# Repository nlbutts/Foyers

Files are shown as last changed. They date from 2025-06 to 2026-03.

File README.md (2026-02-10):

# Foyers / BackPorch Project

The Foyers/BackPorch system is an STM32-based hardware ecosystem designed for FRC robot sensing and control, featuring CAN communication with a built-in bootloader.

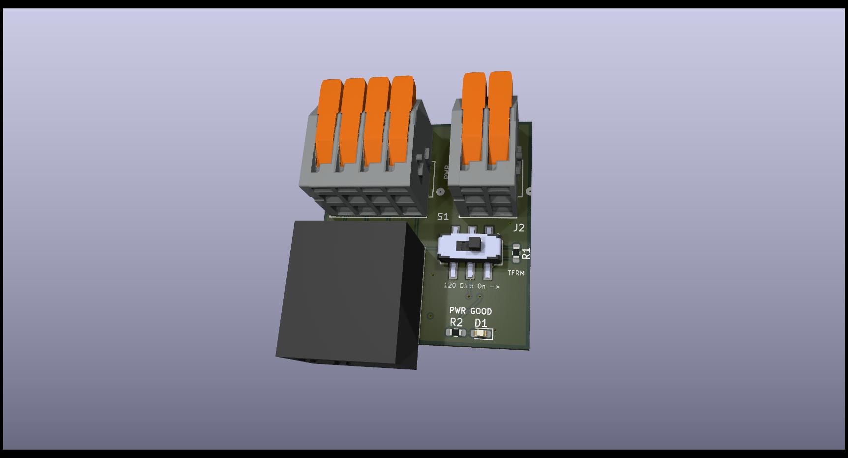
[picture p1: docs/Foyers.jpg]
Foyer Board


## Hardware Overview

### Foyer Distribution Board
The Foyer board serves as the primary distribution point for the system. 
- **Power & CAN Input**: Connects to the main robot power and CAN bus.
- **Power & CAN Exit**: Provides a pass-through for daisy-chaining CAN and power to subsequent devices.
- **Node Interface**: Distributes power and CAN to the BackPorch and sensor nodes.

### BackPorch Main Board
The BackPorch is the central controller board, based on the STM32G0B1 microcontroller. It handles high-level CAN communication, sensor aggregation, and basic power management.

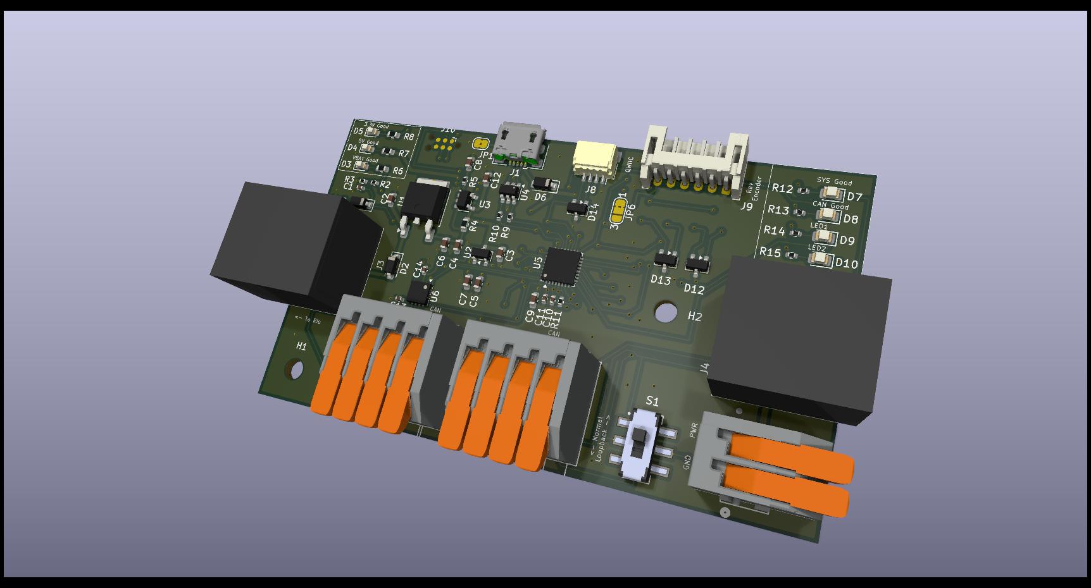
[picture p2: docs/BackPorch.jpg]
BackPorch Header


#### Main Connectors & Pinouts

| Ref | Type | Function | Mating Part |
| --- | --- | --- | --- |
| **J4** | RJ45 | CAN Bus | Standard RJ45 Plug |
| **J9** | JST PH 6-pin | Rev Through Bore Encoder | JST PHR-6 |
| **J10** | USB Micro B | Power / Debug | Standard Micro-USB |
| **J1/J2**| Wago 2601 | Power Input (VBAT/GND) | 24-16 AWG Wire |
| **J3** | Wago 2601 | Motor Output | 24-16 AWG Wire |
| **J6** | Tag-Connect | SWD Programming | TC2030-IDC |

**J4 (RJ45) CAN Pinout:**
- **Pin 1**: CAN High
- **Pin 2**: CAN Low
- **Pin 3**: CAN High Loopback
- **Pin 4**: VBAT
- **Pin 5**: VBAT
- **Pin 6**: Can Low Loopback
- **Pin 7**: GND
- **Pin 8**: GND

**J9 (Rev Through Bore Encoder) Pinout:**
Compatible with the [REV Through Bore Encoder](https://docs.revrobotics.com/rev-crossover-products/sensors/tbe).
- **Pin 1**: 5V Power
- **Pin 2**: Absolute Position (Duty Cycle)
- **Pin 3**: Incremental Channel A
- **Pin 4**: Incremental Channel B
- **Pin 5**: Index (Optional)
- **Pin 6**: GND

### SimpleTOF Board
A compact Time-of-Flight (ToF) distance sensor breakout designed to interface with the BackPorch.

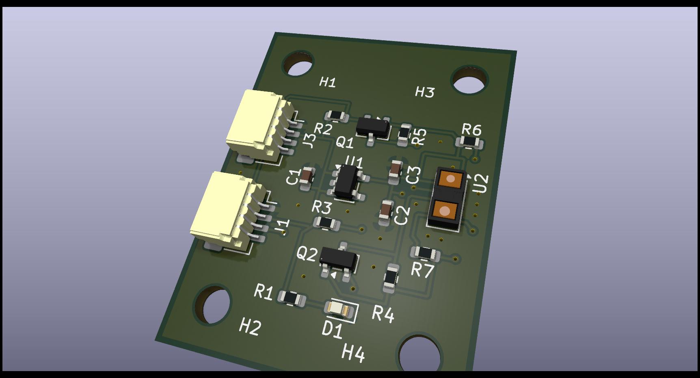
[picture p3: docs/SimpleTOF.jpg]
SimpleTOF


## Software Setup

### Development Environment
This project uses the official STM32 development workflow:

1.  **STM32CubeMX**: Used for low-level hardware configuration (GPIO, CAN, Timers).
    - Open the `.ioc` files in the `software/backporch` or `software/bootloader` directories to modify the hardware configuration.
    - Generate code to update the underlying HAL drivers.
2.  **Visual Studio Code**: The recommended IDE for code development.
    - Use the **STM32 VS Code Extension** to compile the project.
    - Ensure `arm-none-eabi-gcc` is installed and in your PATH.
    - Build using the `CMake` workflow provided by the extension.

## Bootloader & Monitoring Utility

The `software/can_mon/bp_debug.py` program is a multi-purpose Python utility for interacting with the hardware over CAN.

### Script Purpose
- **CAN Monitor**: Provides a real-time GUI to view telemetry from discovered devices (Voltage, Current, Temp, Distance, Encoder position).
- **Firmware Updater**: Acts as the host tool for the CAN bootloader, allowing you to stream `.bin` files to a target device ID and commit them to flash.
- **Status Broadcasts**: Decodes the WPILib-formatted CAN frames used by the system.

### Usage
```bash
python software/can_mon/bp_debug.py
```
*Note: Requires `python-can` and `tkinter` libraries. Ensure your CAN adapter is configured (default: SLSAN on COM5).*

## System Architecture

System Architecture

The system follows a modular architecture where multiple sensor nodes (Foyers) communicate with the BackPorch controller over a shared CAN bus, which then interfaces with the Robot Controller.

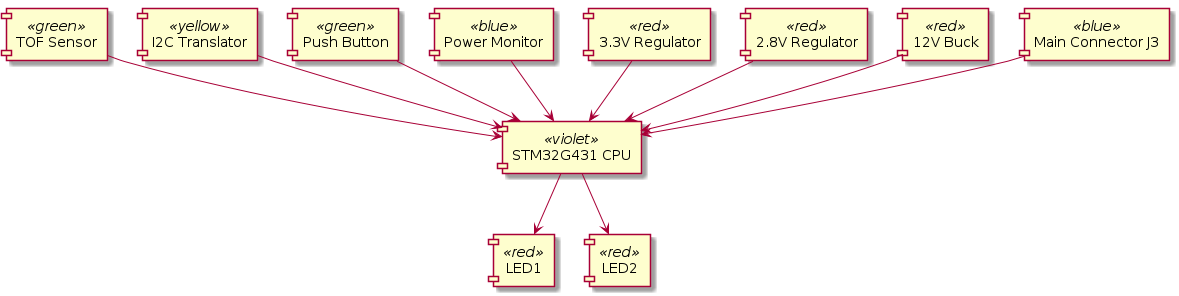
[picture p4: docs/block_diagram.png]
Block Diagram

These are similar to the SWYFT CAN wiring devices

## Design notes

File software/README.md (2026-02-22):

# STM32G0B1 CAN Bootloader

This project implements a CAN-based bootloader for the STM32G0B1 using the WPIlib CAN addressing scheme.

## Overview
- **Bootloader Size**: 32KB (`0x08000000` - `0x08007FFF`)
- **Application App Size**: 96KB (`0x08008000` - `0x0801FFFF`)
- **RAM Buffer**: 96KB Reserved at `0x2000C000`

## CAN Protocol
The bootloader uses 29-bit Extended IDs following the WPIlib format.
- **Device Type**: `10` (Miscellaneous)
- **Manufacturer**: `42` (Custom)
- **Device ID**: `0` (Default)

### CAN ID Structure
| Bits [28:24] | Bits [23:16] | Bits [15:10] | Bits [9:6] | Bits [5:0] |
|---|---|---|---|---|
| Device Type  | Manufacturer | API Class | API Index  | Device ID  |
| `0x0A` (10)  | `0x2A` (42)  | *Variable* | `0` | `0` |

### API Classes
1. **Control (0x01)**: Command and Status operations (Bootloader).
2. **Data (0x02)**: Streaming binary application data (Bootloader).
5. **Status (0x05)**: Application runtime status messages.

### Commands
#### 1. Start Session
Prepare bootloader to receive new data.
- **ID**: `0x0A2A0400` (Class 1)
- **Data[0]**: `0x01` (CMD_START)
- **Response**: `0xAA 0x00 ...` (ACK)

#### 2. Streaming Data
Send application binary in 8-byte chunks.
- **ID**: `0x0A2A0800` (Class 2)
- **Data**: `[Bytes 0-7]`
- **Note**: Must start sending from the beginning of the binary file.

#### 3. Commit & Flash
Verify integrity and program to Flash.
- **ID**: `0x0A2A0400` (Class 1)
- **Data**: `0x02` (CMD_COMMIT) + `[CRC32 (4 Bytes, Little Endian)]`
- **Response**: 
    - `0xAA 0x01 ...` (Success/Rebooting)
    - `0xAA 0xEE ...` (CRC Failure)

## CRC Verification
The bootloader uses the standard **STM32 Hardware CRC-32** unit.
- **Polynomial**: `0x04C11DB7` (Ethernet Standard)
- **Initial Value**: `0xFFFFFFFF`
- **Input/Output Inversion**: None
- **Input Format**: 32-bit Words (Big Endian logic in terms of word feed, but Little Endian memory. Standard STM32 HAL behavior).

### Calculating CRC for Build
The Host tool must calculate the CRC32 of the binary file to send in the `COMMIT` command.
**Python Example**:
```python
import zlib

def calc_crc(file_path):
    with open(file_path, 'rb') as f:
        data = f.read()
    
    # STM32 CRC-32 is slightly different from zlib.crc32 (which is usually inverted).
    # However, STM32 HAL with Default settings is:
    # Poly: 0x04C11DB7, Init: 0xFFFFFFFF
    # Software equivalent usually requires custom implementation or 'crcmod'.
    # Standard MPEG-2 CRC-32 is often close.
    pass
```
*Note*: The easiest way to verify the CRC algorithm matches is to run a small known binary on the chip and print the calculated CRC via debug, then match your script to it.

### CRC Placement in Binary
For the *Boot-Up Verification* (checking app validity on power-on), the bootloader stores the CRC in a special **Boot Config** flash page at `0x08007800`.
- You **do not** need to embed the CRC in the application binary file itself.
- The Host Tool sends the CRC in the `COMMIT` packet.
- The Bootloader validates the RAM buffer against this CRC.
- If match, it flashes the App **AND** updates the Boot Config with this CRC.

## Testing Walkthrough
1. **Build**: Compile the Bootloader.
2. **Flash**: Load `bootloader.elf` to the target.
3. **Connect**: Use a USB-CAN Adapter (e.g., PCAN, CandleLight) with 500kbps (or configured baud).
4. **Commands**:
    - Send `START` (`0x0A2A0400` -> `01`)
    - Send `DATA` chunks (`0x0A2A0800` -> `...`)
    - Send `COMMIT` (`0x0A2A0400` -> `02 AA BB CC DD`)
5. **Verify**: Device should reboot and run application.

## Application Status Messages (API Class 5)
When running in application mode, the device broadcasts status messages using API Class 5.

### 1. Software Version (Index 0)
- **ID**: `0x0A2A1400`
- **Data**:
    - **Byte 0-3**: Unique 32-bit ID (MurmurHash3 of CPU Serial, Little Endian)
    - **Byte 4**: Version Info
        - Bit 0: Mode (0: Bootloader, 1: Application)
        - Bits 1-3: Major Version
        - Bits 4-7: Minor Version
    - **Byte 5-7**: 24-bit build number (Little Endian)

### 2. General Status (Index 1)
- **ID**: `0x0A2A1440`
- **Data**:
    - **Byte 0-3**: Unique 32-bit ID (MurmurHash3 of CPU Serial, Little Endian)
    - **Byte 4**: Current (mA)
    - **Byte 5-6**: Voltage (mV, Little Endian)
    - **Byte 7**: Temperature (°C)

### 3. TOF Status (Index 2)
- **ID**: `0x0A2A1480`
- **Data**:
    - **Byte 0**: ST TOF API Status
    - **Byte 1**: Bit 0 SDA limit switch, Bit 1 SCL limit switch
    - **Byte 2-3**: Distance (mm, Little Endian)
    - **Byte 4-5**: Ambient Mcps (Little Endian)
    - **Byte 6-7**: Signal Mcps (Little Endian)

### 4. Encoder Status (Index 3)
- **ID**: `0x0A2A14C0`
- **Data**:
    - **Byte 0-1**: Encoder 1 Absolute Position (0.01°, Little Endian)
    - **Byte 2-3**: Encoder 1 Incremental Position (counts, Little Endian)
    - **Byte 4-5**: Encoder 2 Absolute Position (0.01°, Little Endian)
    - **Byte 6-7**: Encoder 2 Incremental Position (counts, Little Endian)

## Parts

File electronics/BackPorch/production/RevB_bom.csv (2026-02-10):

Designator | Footprint | Quantity | Value | LCSC Part #
C1 | 0402 | 1 | 1u | C52923
C10, C11, C13, C14 | 0402 | 4 | 0.1u | C1525
C12, C8 | 0603 | 2 | 2.2u | C23630
C2, C4, C6 | 0603 | 3 | 10u | C96446
C3, C5, C7, C9 | 0603 | 4 | 4.7u | C19666
D1 | D_SOD-123 | 1 | D_Zener | C2105
D10, D9 | 0805 | 2 | LED | C34499
D11, D12, D13, D14 | SOT-23 | 4 | SP0502BAHT | C32677
D2, D6 | D_SOD-123 | 2 | D_Schottky | C8598
D3, D4, D5 | 0603 | 3 | LED | C2286
D7, D8 | 0805 | 2 | LED | C2297
J1 | USB_Micro-B_Amphenol_10118193-0001LF_Horizontal | 1 | USB_B_Micro | C132562
J3, J4 | AMPHENOL_54602-908LF | 2 | RJ45 | C2847314
J8 | JST_SH_SM04B-SRSS-TB_1x04-1MP_P1.00mm_Horizontal | 1 | Conn_01x04 | C160404
J9 | JST_PH_S6B-PH-K_1x06_P2.00mm_Horizontal | 1 | Conn_01x06 | C157920
R1 | 0805 | 1 | 49.9 | C17720
R10, R9 | 0402 | 2 | 22 | C25092
R11 | 0402 | 1 | 4.7k | C25900
R12, R13, R14, R15 | 0402 | 4 | 49.9 | C25120
R2 | 0402 | 1 | 10k | C25744
R3, R5 | 0402 | 2 | 1k | C11702
R4 | 0603 | 1 | 1 | C22936
R6 | 0603 | 1 | 680 | C23228
R7, R8 | 0603 | 2 | 330 | C23138
S1 | SW_JS202011SCQN | 1 | JS202011SCQN | C221666
U1 | TO-252-2 | 1 | L78M05ABDT-TR | C58069
U2 | SOT-23 | 1 | XC6206P332MR-G | C5446
U3 | SOT-23-5 | 1 | INA180A1 | C122228
U4 | SOT-23-6 | 1 | USBLC6-2SC6 | C7519
U5 | QFN-32-1EP_5x5mm_P0.5mm_EP3.45x3.45mm | 1 | STM32G0B1KBUx | C5159549
U6 | VSON-8-1EP_3x3mm_P0.65mm_EP1.6x2.4mm | 1 | TCAN1044A-Q1 | C3234119

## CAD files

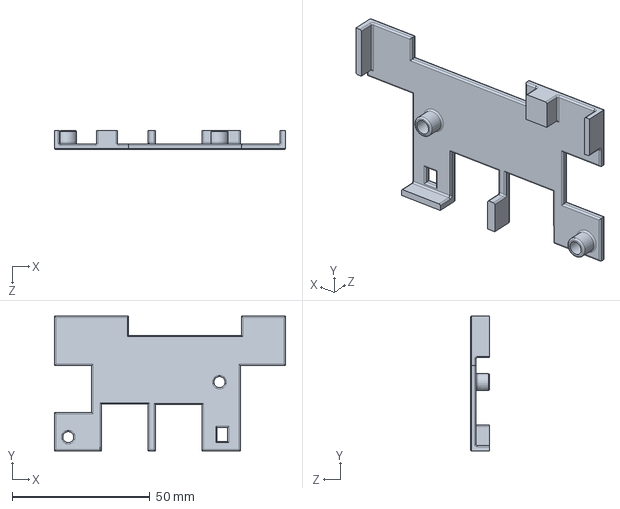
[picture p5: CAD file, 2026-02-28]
mechanical/Backporch_holder_top.SLDPRT
84.0 x 49.0 x 7.00 mm

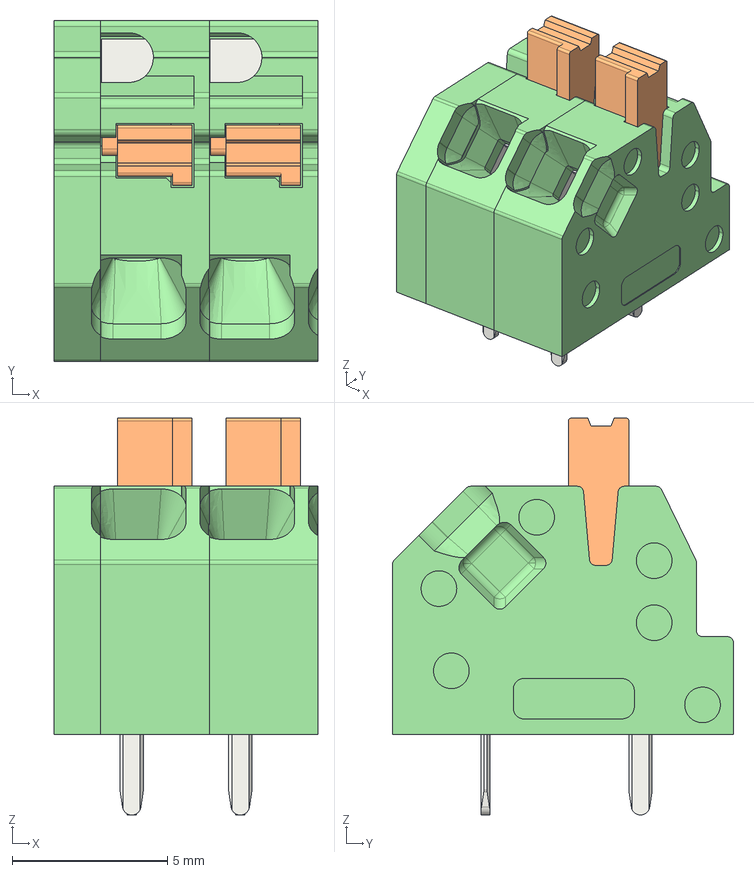
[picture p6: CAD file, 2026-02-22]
parts/Step/pxc_1862042_01_01_SPTAF-1-2-3-5-EL_3D.stp
8.50 x 11.0 x 12.8 mm

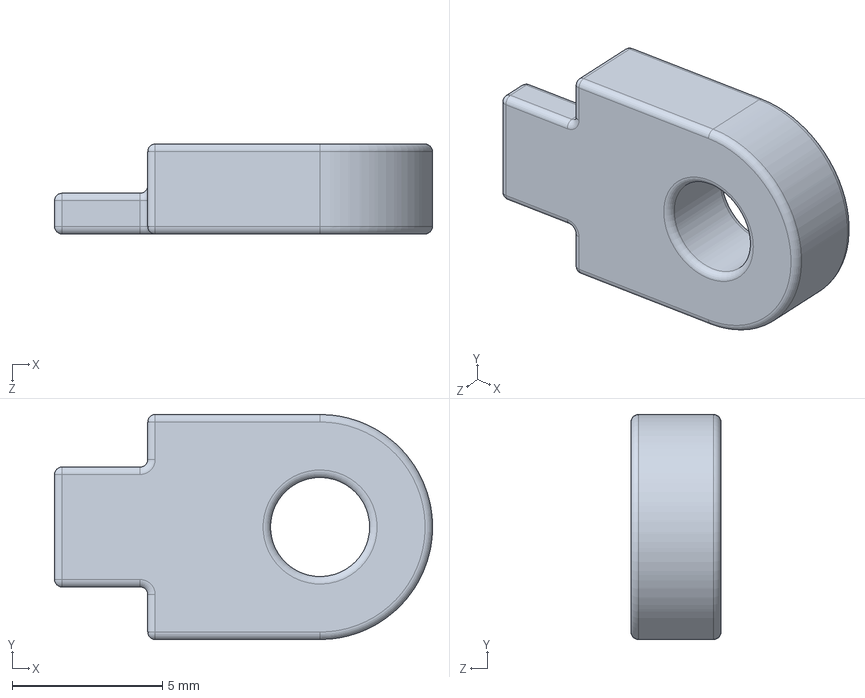
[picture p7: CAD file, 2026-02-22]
mechanical/Foyer_baseplate_pcb_holder.SLDPRT
12.6 x 7.50 x 3.00 mm

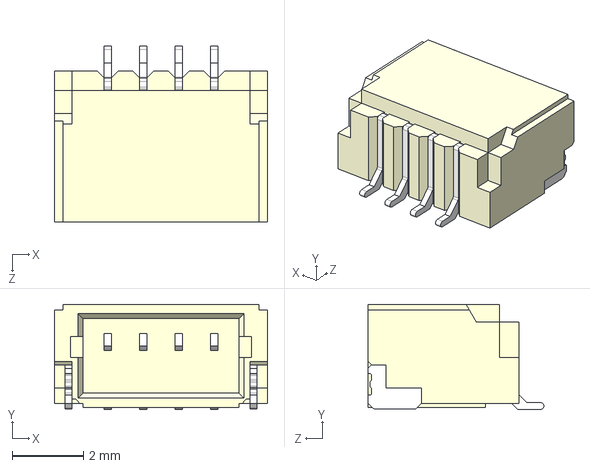
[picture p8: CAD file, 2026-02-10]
parts/Step/SM04B-SRSS-TB.STEP
6.00 x 2.96 x 4.95 mm

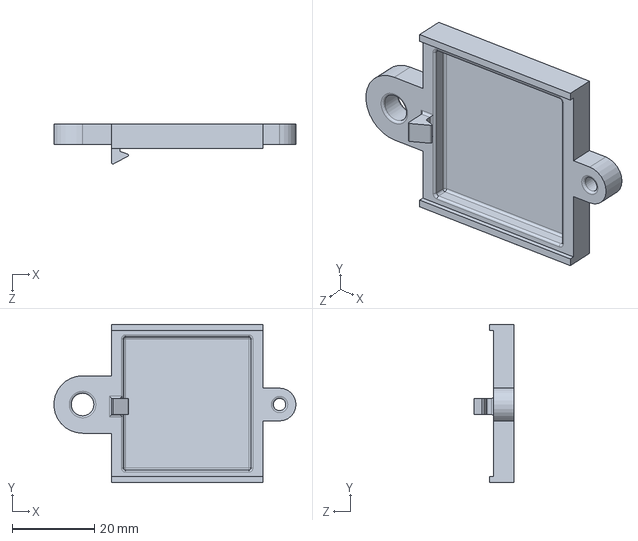
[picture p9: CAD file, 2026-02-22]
mechanical/Foyer_baseplate.SLDPRT
59.0 x 38.5 x 9.83 mm

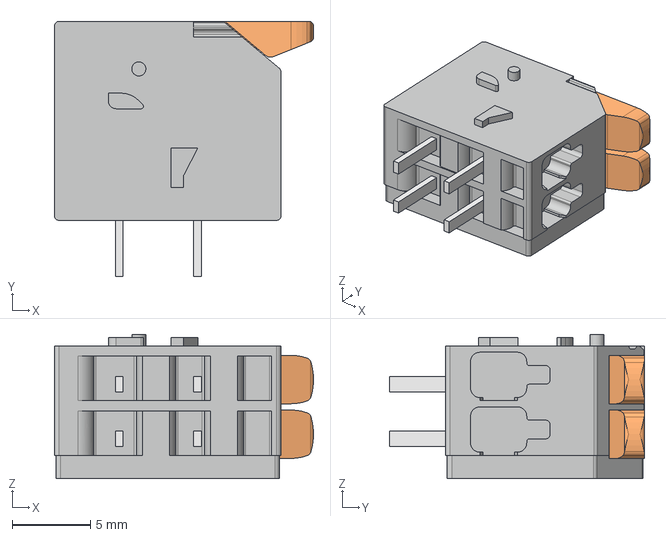
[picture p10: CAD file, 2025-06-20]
parts/Step/2601-1102.stp
16.6 x 16.4 x 9.25 mm

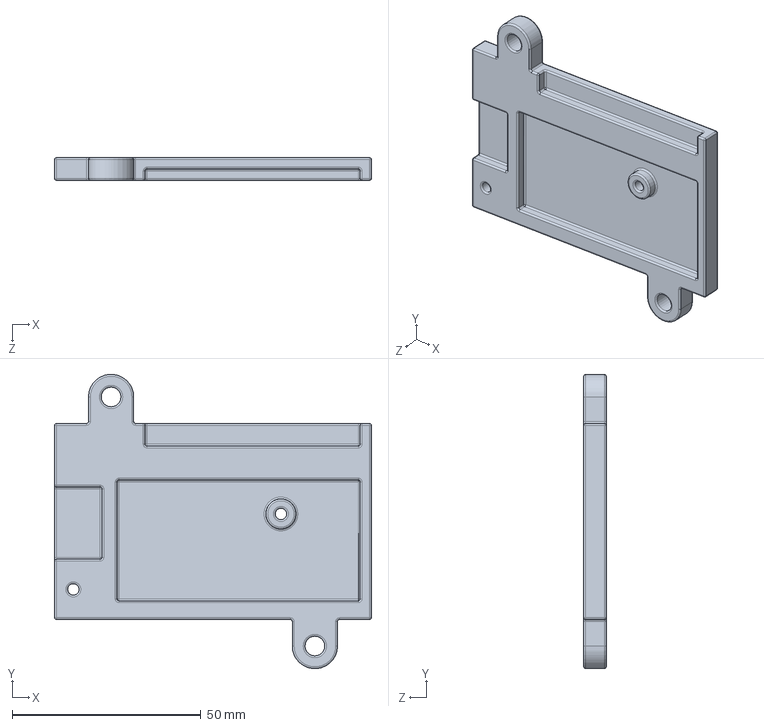
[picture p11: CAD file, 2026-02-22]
mechanical/Backporch_holder.SLDPRT
84.0 x 78.0 x 6.00 mm

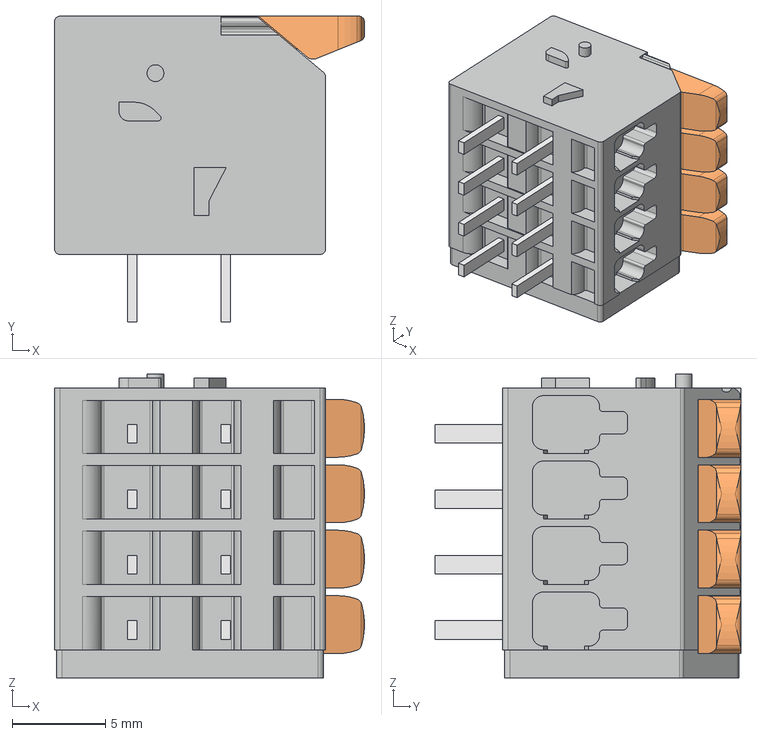
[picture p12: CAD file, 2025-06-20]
parts/Step/2601-1104.stp
16.6 x 16.4 x 16.2 mm

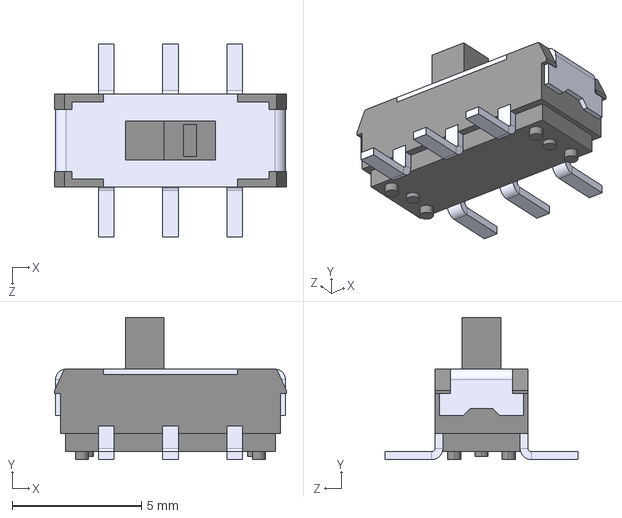
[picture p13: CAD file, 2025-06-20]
parts/Step/JS202011SCQN.step
8.99 x 5.51 x 7.49 mm

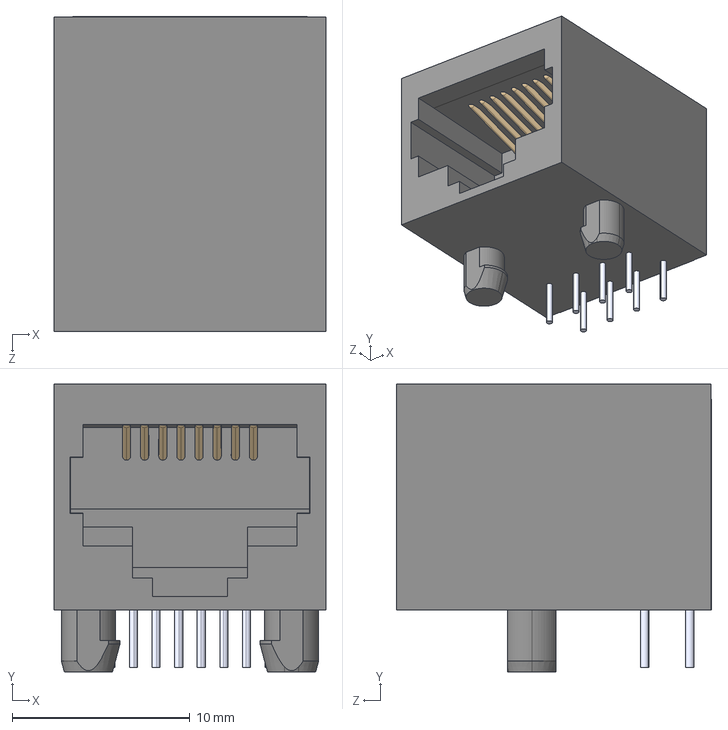
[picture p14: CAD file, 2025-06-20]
parts/Step/54602-908LF.step
15.3 x 16.2 x 17.7 mm

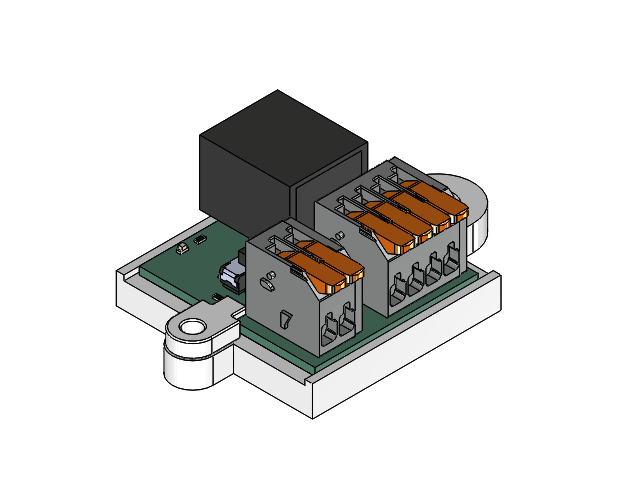
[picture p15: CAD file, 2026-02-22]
mechanical/Foyer.SLDASM
LED_0603_1608Metric.step
JS202011SCQN.step
2601-1102.step
R_0603_1608Metric.step x 2
2601-1104.step
54602-908LF.step
Foyers_PCB.step
Foyer_baseplate
Foyer_baseplate_pcb_holder

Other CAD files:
mechanical/Backporch_holder_top.3mf

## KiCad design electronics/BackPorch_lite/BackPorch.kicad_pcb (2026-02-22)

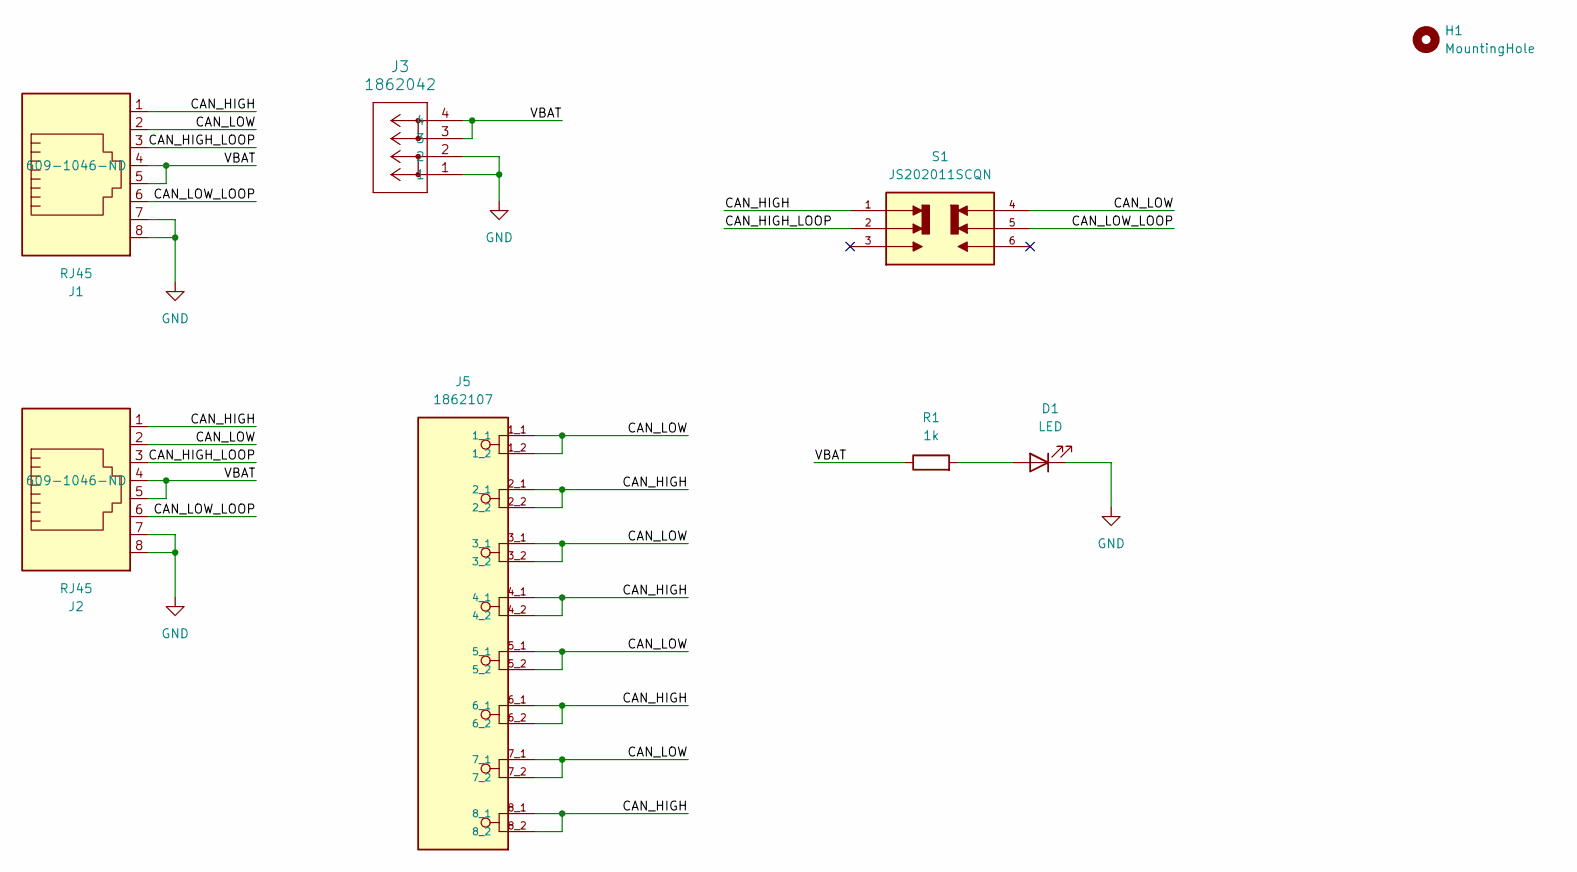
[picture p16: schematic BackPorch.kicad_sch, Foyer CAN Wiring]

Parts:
D1: LED; LED_0603_1608Metric_Pad1.05x0.95mm_HandSolder
H1: MountingHole; MountingHole_3.2mm_M3
J1, J2: RJ45; AMPHENOL_54602-908LF; Digikey 609-1046-ND
J3: 1862042; CONN_1862042
J5: 1862107; PHOENIX_1862107
R1: 1k; R_0603_1608Metric_Pad0.98x0.95mm_HandSolder
S1: JS202011SCQN; SW_JS202011SCQN; PARTREV 26 May 22

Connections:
/CAN_HIGH: J1.1, J2.1, J5.2_1, J5.2_2, J5.4_1, J5.4_2, J5.6_1, J5.6_2, J5.8_1, J5.8_2, S1.1
/CAN_HIGH_LOOP: J1.3, J2.3, S1.2
/CAN_LOW: J1.2, J2.2, J5.1_1, J5.1_2, J5.3_1, J5.3_2, J5.5_1, J5.5_2, J5.7_1, J5.7_2, S1.4
/CAN_LOW_LOOP: J1.6, J2.6, S1.5
/VBAT: J1.4, J1.5, J2.4, J2.5, J3.3, J3.4, R1.1
GND: D1.1 (K), J1.7, J1.8, J2.7, J2.8, J3.1, J3.2
unnamed: D1.2 (A), R1.2

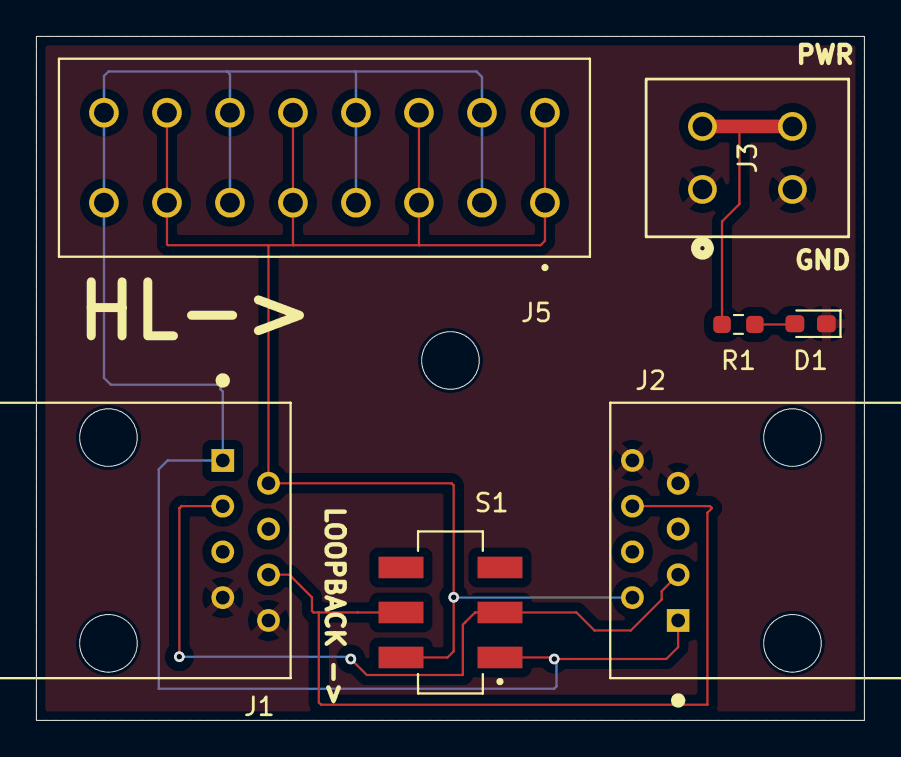
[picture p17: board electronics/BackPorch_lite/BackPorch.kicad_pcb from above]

Board: 2 copper layers, 46.0 x 38.0 mm, 8 parts (0 on the bottom side), 7 nets.

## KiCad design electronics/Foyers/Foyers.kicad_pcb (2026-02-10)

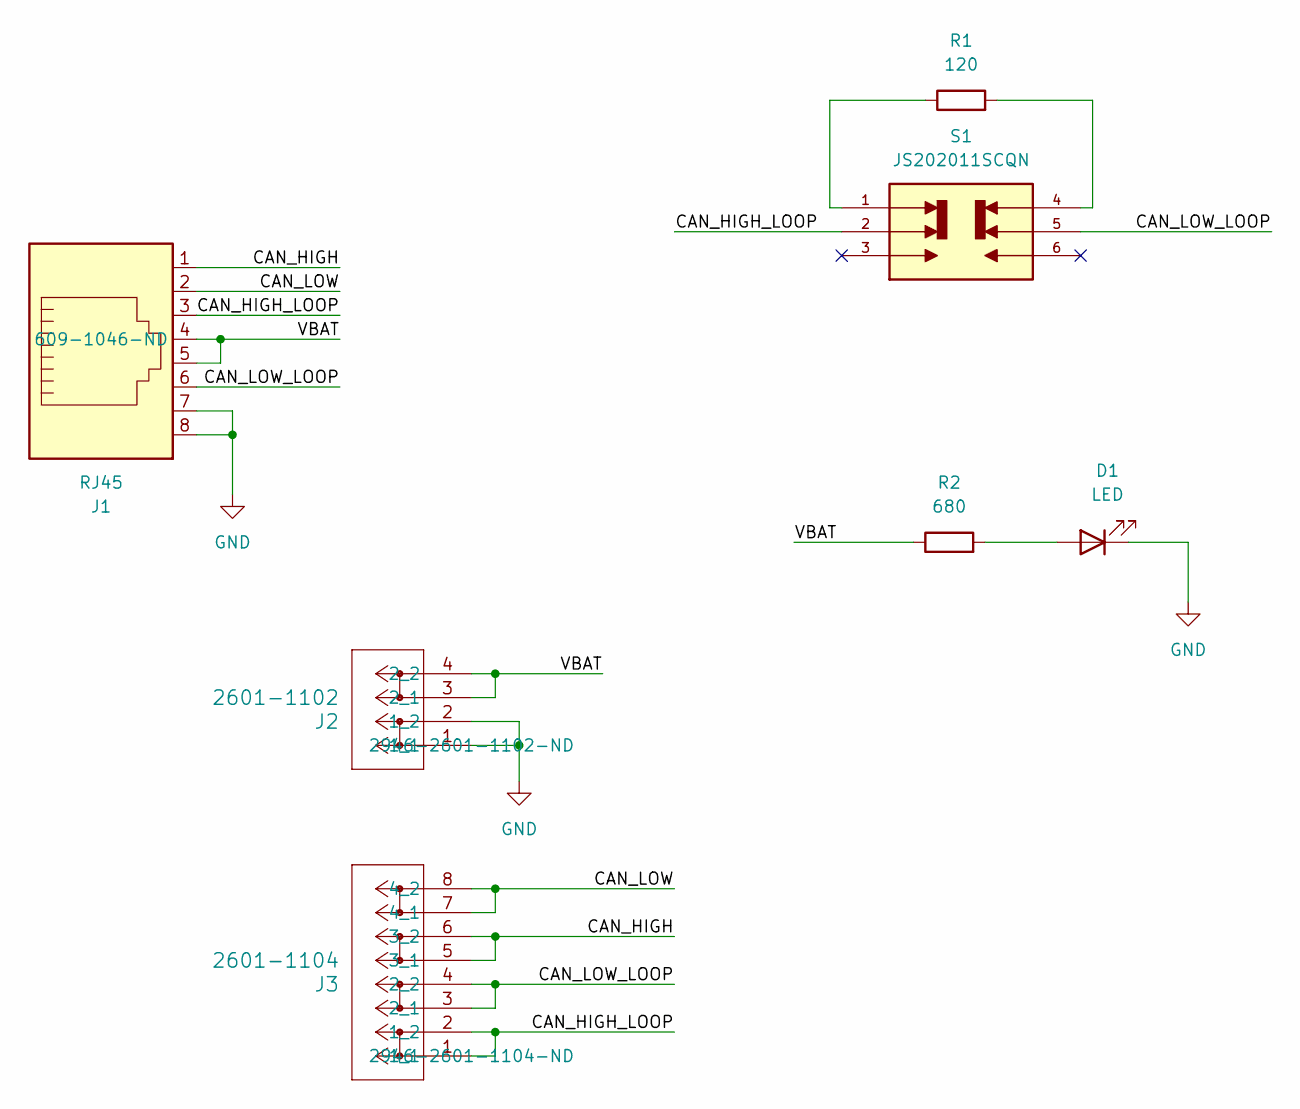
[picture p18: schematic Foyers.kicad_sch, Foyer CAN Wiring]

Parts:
D1: LED; LED_0603_1608Metric_Pad1.05x0.95mm_HandSolder
J1: RJ45; AMPHENOL_54602-908LF; Digikey 609-1046-ND
J2: 2601-1102; CONN2_2601-1102_WAG; Digikey 2946-2601-1102-ND
J3: 2601-1104; CONN4_2601-1104_WAG; Digikey 2946-2601-1104-ND
R1: 120; R_0603_1608Metric_Pad0.98x0.95mm_HandSolder
R2: 680; R_0603_1608Metric_Pad0.98x0.95mm_HandSolder
S1: JS202011SCQN; SW_JS202011SCQN; PARTREV 26 May 22; Digikey 401-2002-2-ND

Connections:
/CAN_HIGH: J1.1, J3.5 (3_1), J3.6 (3_2)
/CAN_HIGH_LOOP: J1.3, J3.1 (1_1), J3.2 (1_2), S1.2
/CAN_LOW: J1.2, J3.7 (4_1), J3.8 (4_2)
/CAN_LOW_LOOP: J1.6, J3.3 (2_1), J3.4 (2_2), S1.5
/VBAT: J1.4, J1.5, J2.3 (2_1), J2.4 (2_2), R2.1
GND: D1.1 (K), J1.7, J1.8, J2.1 (1_1), J2.2 (1_2)
unnamed: D1.2 (A), R2.2
unnamed: R1.1, S1.1
unnamed: R1.2, S1.4

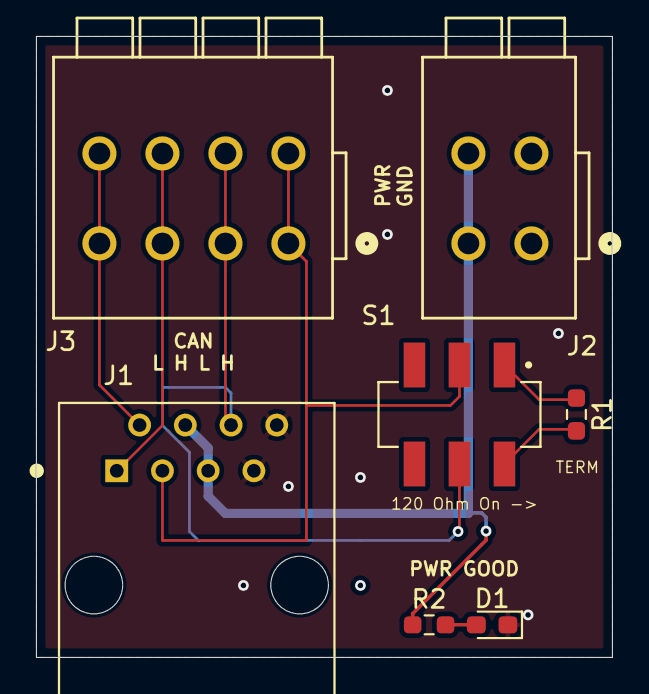
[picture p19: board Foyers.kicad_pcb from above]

Board: 2 copper layers, 32.0 x 34.5 mm, 7 parts (0 on the bottom side), 9 nets.

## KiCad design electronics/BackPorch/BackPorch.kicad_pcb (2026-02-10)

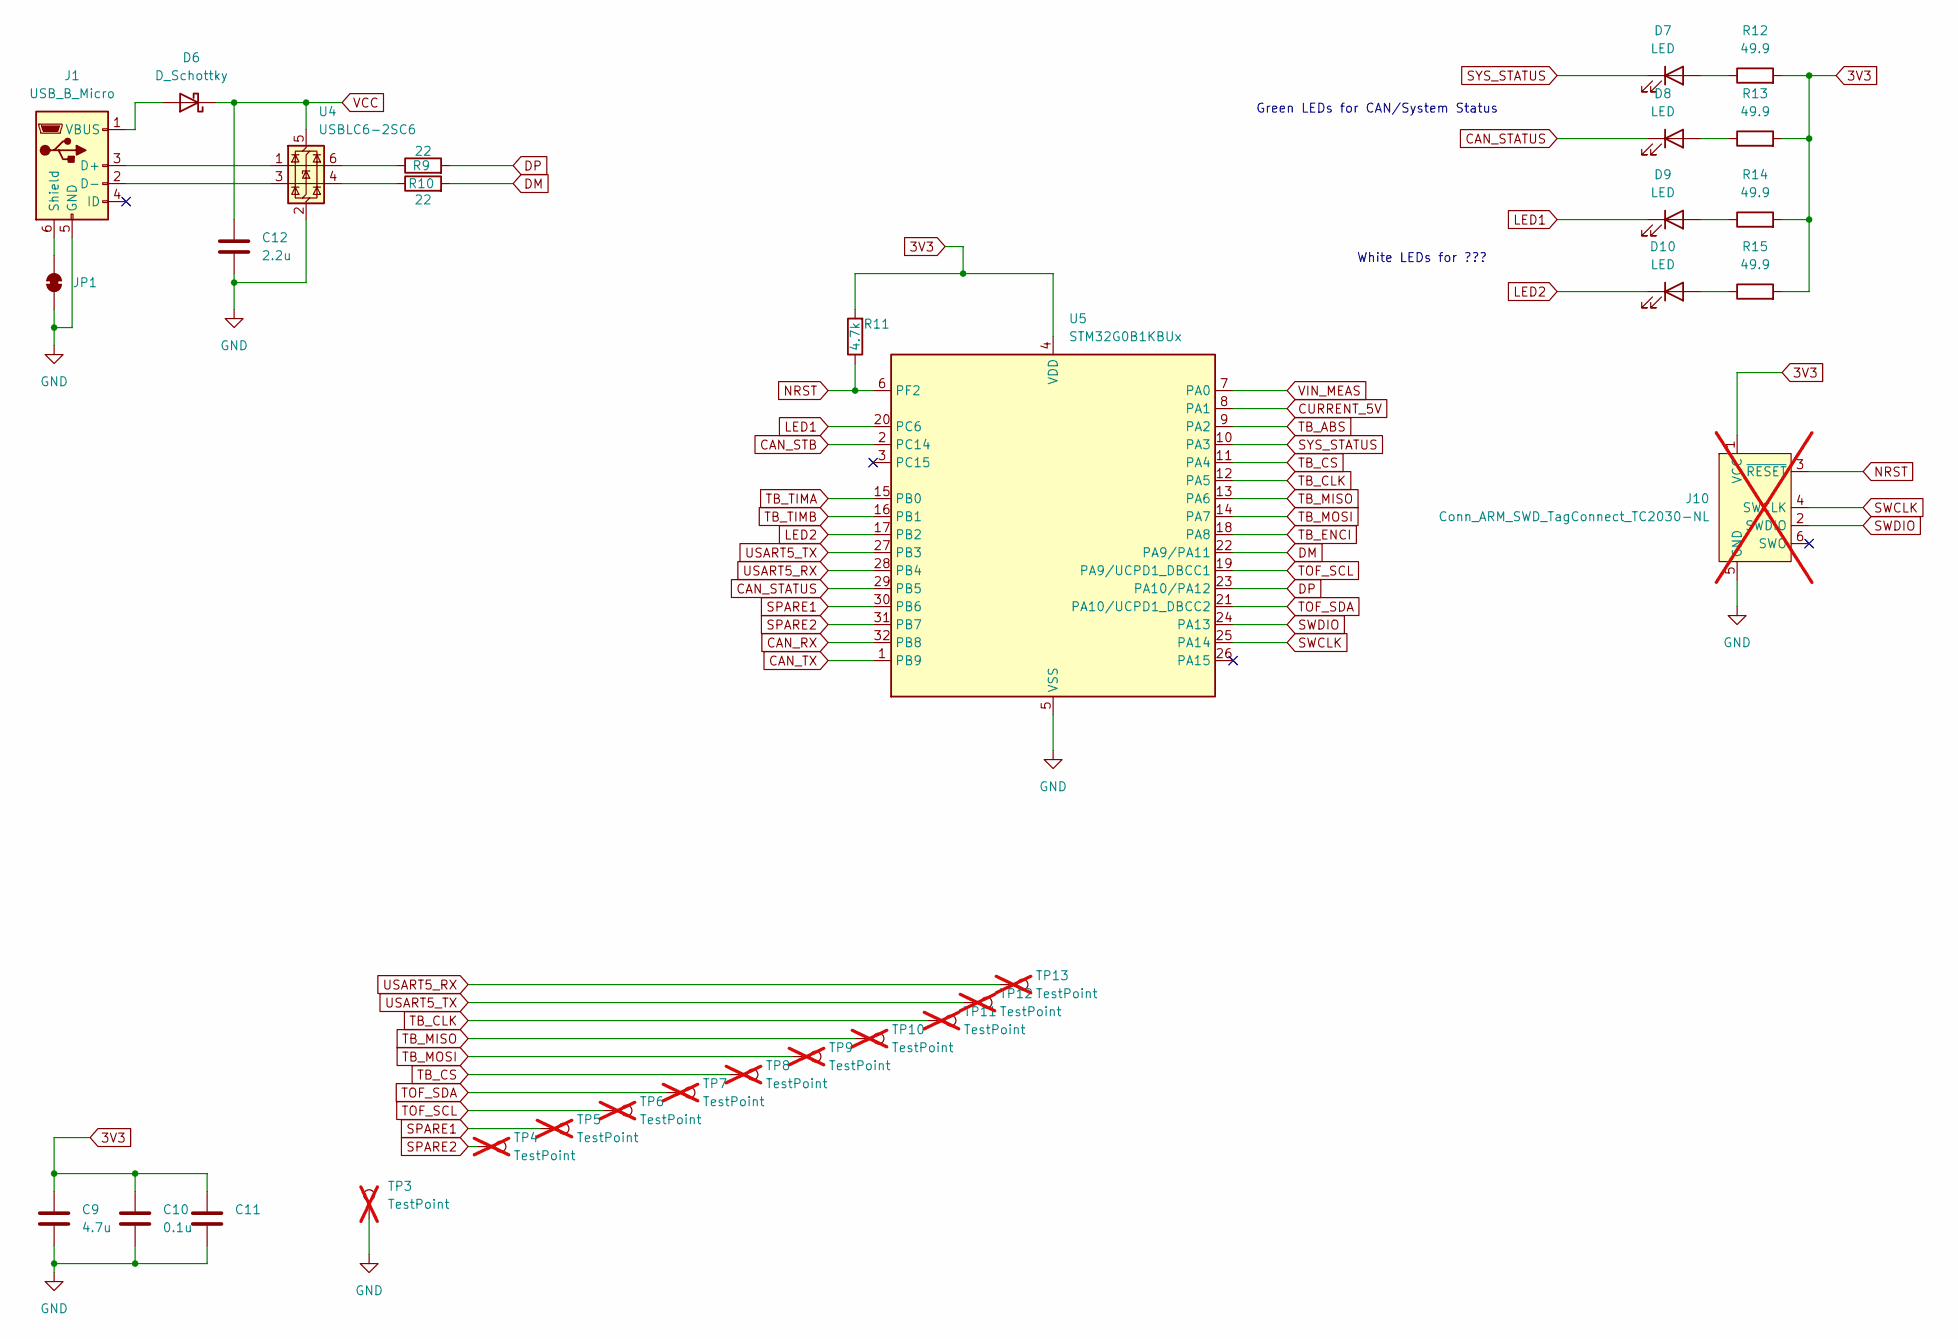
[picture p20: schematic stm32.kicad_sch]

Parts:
C9: 4.7u; C_0603_1608Metric; JLC C19666
C10, C11: 0.1u; C_0402_1005Metric; JLC C1525
C12: 2.2u; C_0603_1608Metric; JLC C23630
D6: D_Schottky; D_SOD-123; Digikey B0540W-FDICT-ND
D7, D8: LED; LED_0805_2012Metric; JLC C2297
D9, D10: LED; LED_0805_2012Metric; JLC C34499
J1: USB_B_Micro; USB_Micro-B_Amphenol_10118193-0001LF_Horizontal; JLC C132562
J10: Conn_ARM_SWD_TagConnect_TC2030-NL; Tag-Connect_TC2030-IDC-NL_2x03_P1.27mm_Vertical; not fitted
JP1: SolderJumper_2_Bridged; SolderJumper-2_P1.3mm_Bridged2Bar_RoundedPad1.0x1.5mm
R9, R10: 22; R_0402_1005Metric; JLC C25092
R11: 4.7k; R_0402_1005Metric; JLC C25900
R12, R13, R14, R15: 49.9; R_0402_1005Metric; JLC C25120
TP3, TP4, TP5, TP6, TP7, TP8, TP9, TP10, TP11, TP12, TP13: TestPoint; TestPoint_Pad_D1.0mm; not fitted
U4: USBLC6-2SC6; SOT-23-6; JLC C7519
U5: STM32G0B1KBUx; QFN-32-1EP_5x5mm_P0.5mm_EP3.45x3.45mm; JLC C5159549

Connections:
3V3: C9.1, C10.1, C11.1, J10.1 (VCC), R11.2, R12.2, R13.2, R14.2, R15.2, U5.4 (VDD); also elsewhere on the board
CAN_RX: U5.32 (PB8); also elsewhere on the board
CAN_STATUS: D8.1 (K), U5.29 (PB5)
CAN_STB: U5.2 (PC14); also elsewhere on the board
CAN_TX: U5.1 (PB9); also elsewhere on the board
CURRENT_5V: U5.8 (PA1); also elsewhere on the board
DM: R10.2, U5.22 (PA9/PA11)
DP: R9.2, U5.23 (PA10/PA12)
GND: C9.2, C10.2, C11.2, C12.1, J1.5 (GND), J10.5 (GND), JP1.1 (A), TP3.1, U4.2 (GND), U5.5 (VSS), U5.33 (VSS); also elsewhere on the board
LED1: D9.1 (K), U5.20 (PC6)
LED2: D10.1 (K), U5.17 (PB2)
NRST: J10.3 (~RESET), R11.1, U5.6 (PF2)
unnamed: D6.2 (A), J1.1 (VBUS)
unnamed: D7.2 (A), R12.1
unnamed: D8.2 (A), R13.1
unnamed: D9.2 (A), R14.1
unnamed: D10.2 (A), R15.1
unnamed: J1.6 (Shield), JP1.2 (B)
unnamed: R9.1, U4.6 (I/O1)
unnamed: R10.1, U4.4 (I/O2)
SPARE1: TP5.1, U5.30 (PB6)
SPARE2: TP4.1, U5.31 (PB7)
SWCLK: J10.4 (SWCLK), U5.25 (PA14)
SWDIO: J10.2 (SWDIO), U5.24 (PA13)
SYS_STATUS: D7.1 (K), U5.10 (PA3)
TB_ABS: U5.9 (PA2); also elsewhere on the board
TB_CLK: TP11.1, U5.12 (PA5); also elsewhere on the board
TB_CS: TP8.1, U5.11 (PA4); also elsewhere on the board
TB_ENCI: U5.18 (PA8); also elsewhere on the board
TB_MISO: TP10.1, U5.13 (PA6); also elsewhere on the board
TB_MOSI: TP9.1, U5.14 (PA7); also elsewhere on the board
TB_TIMA: U5.15 (PB0); also elsewhere on the board
TB_TIMB: U5.16 (PB1); also elsewhere on the board
TOF_SCL: TP6.1, U5.19 (PA9/UCPD1_DBCC1); also elsewhere on the board
TOF_SDA: TP7.1, U5.21 (PA10/UCPD1_DBCC2); also elsewhere on the board
USART5_RX: TP13.1, U5.28 (PB4)
USART5_TX: TP12.1, U5.27 (PB3)
VCC: C12.2, D6.1 (K), U4.5 (VBUS); also elsewhere on the board
VIN_MEAS: U5.7 (PA0); also elsewhere on the board

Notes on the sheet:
Green LEDs for CAN/System Status
White LEDs for ???

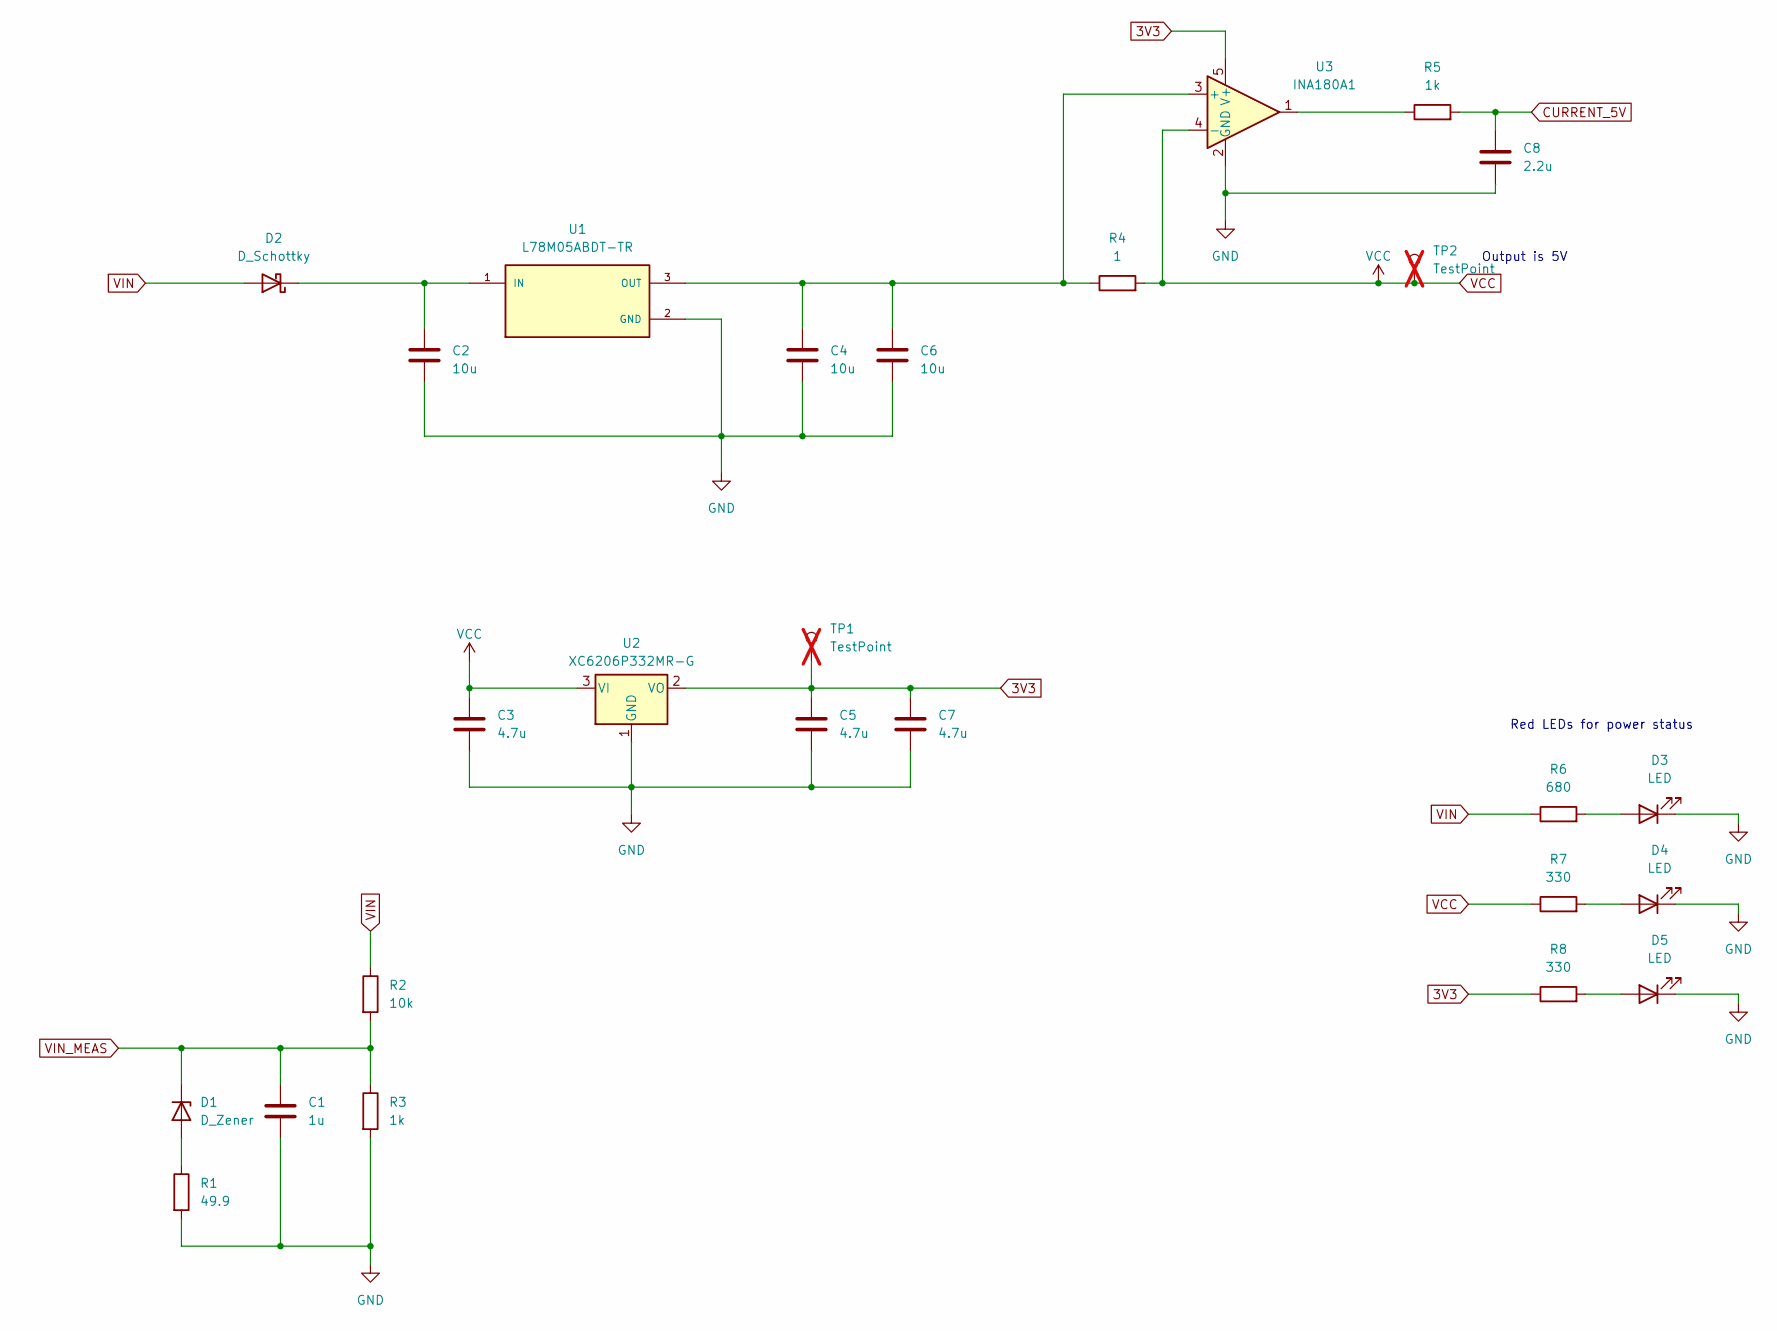
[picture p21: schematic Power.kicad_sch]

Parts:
C1: 1u; C_0402_1005Metric; JLC C52923
C2, C4, C6: 10u; C_0603_1608Metric; Digikey 490-5523-1-ND
C3, C5, C7: 4.7u; C_0603_1608Metric; JLC C19666
C8: 2.2u; C_0603_1608Metric; JLC C23630
D1: D_Zener; D_SOD-123; JLC C2105
D2: D_Schottky; D_SOD-123; Digikey B0540W-FDICT-ND
D3, D4, D5: LED; LED_0603_1608Metric; JLC C2286
R1: 49.9; R_0805_2012Metric; JLC C17720
R2: 10k; R_0402_1005Metric; JLC C25744
R3, R5: 1k; R_0402_1005Metric; JLC C11702
R4: 1; R_0603_1608Metric; JLC C22936
R6: 680; R_0603_1608Metric; JLC C23228
R7, R8: 330; R_0603_1608Metric; JLC C23138
TP1, TP2: TestPoint; TestPoint_Pad_D1.0mm; not fitted
U1: L78M05ABDT-TR; TO-252-2; PARTREV 23; JLC C58069
U2: XC6206P332MR-G; SOT-23; JLC C5446
U3: INA180A1; SOT-23-5; JLC C122228

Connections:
3V3: C5.1, C7.1, R8.1, TP1.1, U2.2 (VO), U3.5 (V+); also elsewhere on the board
CURRENT_5V: C8.2, R5.2; also elsewhere on the board
GND: C1.2, C2.2, C3.2, C4.2, C5.2, C6.2, C7.2, C8.1, D3.1 (K), D4.1 (K), D5.1 (K), R1.2, R3.2, U1.2 (GND), U2.1 (GND), U3.2 (GND); also elsewhere on the board
unnamed: D1.2 (A), R1.1
unnamed: C2.1, D2.1 (K), U1.1 (IN)
unnamed: D3.2 (A), R6.2
unnamed: D4.2 (A), R7.2
unnamed: D5.2 (A), R8.2
unnamed: R5.1, U3.1
unnamed: C4.1, C6.1, R4.1, U1.3 (OUT), U3.3 (+)
VCC: C3.1, R4.2, R7.1, TP2.1, U2.3 (VI), U3.4 (-); also elsewhere on the board
VIN: D2.2 (A), R2.1, R6.1; also elsewhere on the board
VIN_MEAS: C1.1, D1.1 (K), R2.2, R3.1; also elsewhere on the board

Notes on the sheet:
Output is 5V
Red LEDs for power status

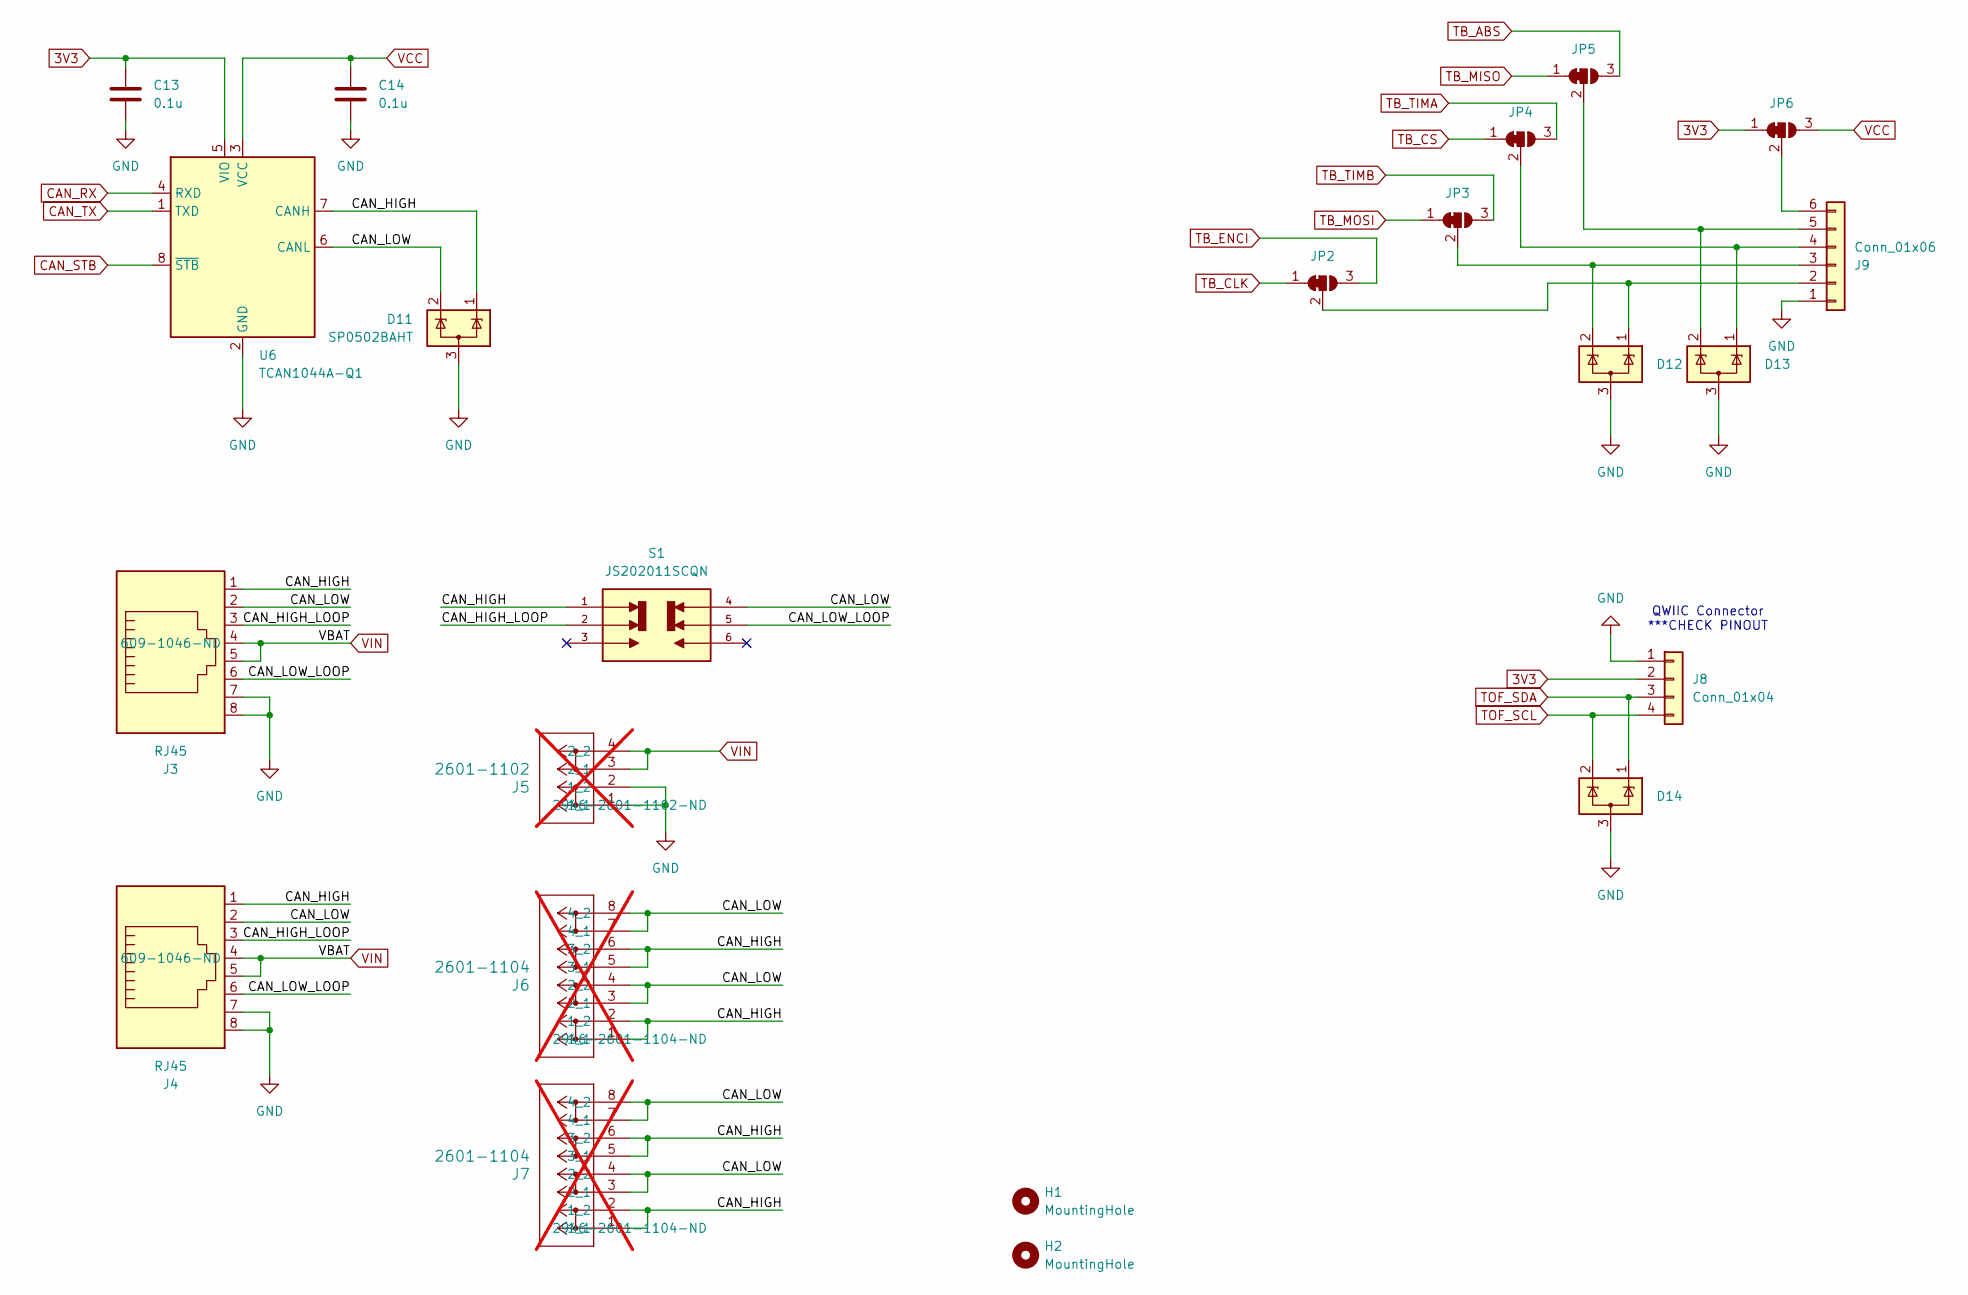
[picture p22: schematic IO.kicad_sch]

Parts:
C13, C14: 0.1u; C_0402_1005Metric; JLC C1525
D11, D12, D13, D14: SP0502BAHT; SOT-23; JLC C32677
H1, H2: MountingHole; MountingHole_3.2mm_M3_DIN965
J3, J4: RJ45; AMPHENOL_54602-908LF; Digikey 609-1046-ND
J5: 2601-1102; CONN2_2601-1102_WAG; Digikey 2946-2601-1102-ND; not fitted
J6, J7: 2601-1104; CONN4_2601-1104_WAG; Digikey 2946-2601-1104-ND; not fitted
J8: Conn_01x04; JST_SH_SM04B-SRSS-TB_1x04-1MP_P1.00mm_Horizontal; Digikey 455-B4B-PH-SM4-TBCT-ND
J9: Conn_01x06; JST_PH_S6B-PH-K_1x06_P2.00mm_Horizontal; JLC C157920
JP2, JP3, JP4, JP5: SolderJumper_3_Bridged12; SolderJumper-3_P1.3mm_Bridged12_RoundedPad1.0x1.5mm
JP6: SolderJumper_3_Bridged12; SolderJumper-3_P1.3mm_Bridged2Bar12_RoundedPad1.0x1.5mm_Num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
S1: JS202011SCQN; SW_JS202011SCQN; PARTREV 26 May 22; JLC C221666
U6: TCAN1044A-Q1; VSON-8-1EP_3x3mm_P0.65mm_EP1.6x2.4mm; JLC C3234119

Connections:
3V3: C13.1, J8.2, JP6.1 (A), U6.5 (VIO); also elsewhere on the board
/IO/CAN_HIGH: D11.1 (K), J3.1, J4.1, J6.1 (1_1), J6.2 (1_2), J6.5 (3_1), J6.6 (3_2), J7.1 (1_1), J7.2 (1_2), J7.5 (3_1), J7.6 (3_2), S1.1, U6.7 (CANH)
/IO/CAN_HIGH_LOOP: J3.3, J4.3, S1.2
/IO/CAN_LOW: D11.2 (K), J3.2, J4.2, J6.3 (2_1), J6.4 (2_2), J6.7 (4_1), J6.8 (4_2), J7.3 (2_1), J7.4 (2_2), J7.7 (4_1), J7.8 (4_2), S1.4, U6.6 (CANL)
/IO/CAN_LOW_LOOP: J3.6, J4.6, S1.5
CAN_RX: U6.4 (RXD); also elsewhere on the board
CAN_STB: U6.8 (~STB); also elsewhere on the board
CAN_TX: U6.1 (TXD); also elsewhere on the board
GND: C13.2, C14.2, D11.3 (A), D12.3 (A), D13.3 (A), D14.3 (A), J3.7, J3.8, J4.7, J4.8, J5.1 (1_1), J5.2 (1_2), J8.1, J9.1, U6.2 (GND); also elsewhere on the board
unnamed: D12.1 (K), J9.2, JP2.2 (C)
unnamed: D12.2 (K), J9.3, JP3.2 (C)
unnamed: D13.1 (K), J9.4, JP4.2 (C)
unnamed: D13.2 (K), J9.5, JP5.2 (C)
unnamed: J9.6, JP6.2 (C)
TB_ABS: JP5.3 (B); also elsewhere on the board
TB_CLK: JP2.1 (A); also elsewhere on the board
TB_CS: JP4.1 (A); also elsewhere on the board
TB_ENCI: JP2.3 (B); also elsewhere on the board
TB_MISO: JP5.1 (A); also elsewhere on the board
TB_MOSI: JP3.1 (A); also elsewhere on the board
TB_TIMA: JP4.3 (B); also elsewhere on the board
TB_TIMB: JP3.3 (B); also elsewhere on the board
TOF_SCL: D14.2 (K), J8.4; also elsewhere on the board
TOF_SDA: D14.1 (K), J8.3; also elsewhere on the board
VCC: C14.1, JP6.3 (B), U6.3 (VCC); also elsewhere on the board
VIN: J3.4, J3.5, J4.4, J4.5, J5.3 (2_1), J5.4 (2_2); also elsewhere on the board

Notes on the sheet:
QWIIC Connector ***CHECK PINOUT

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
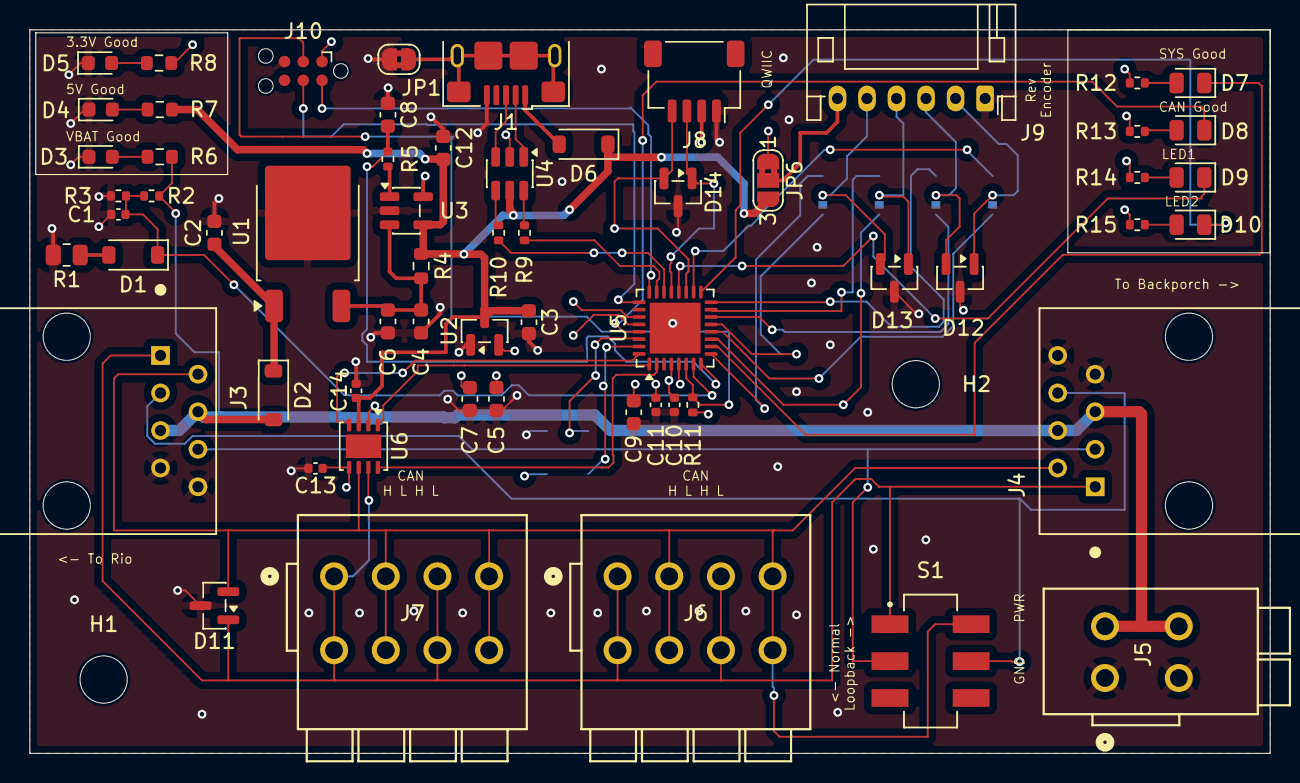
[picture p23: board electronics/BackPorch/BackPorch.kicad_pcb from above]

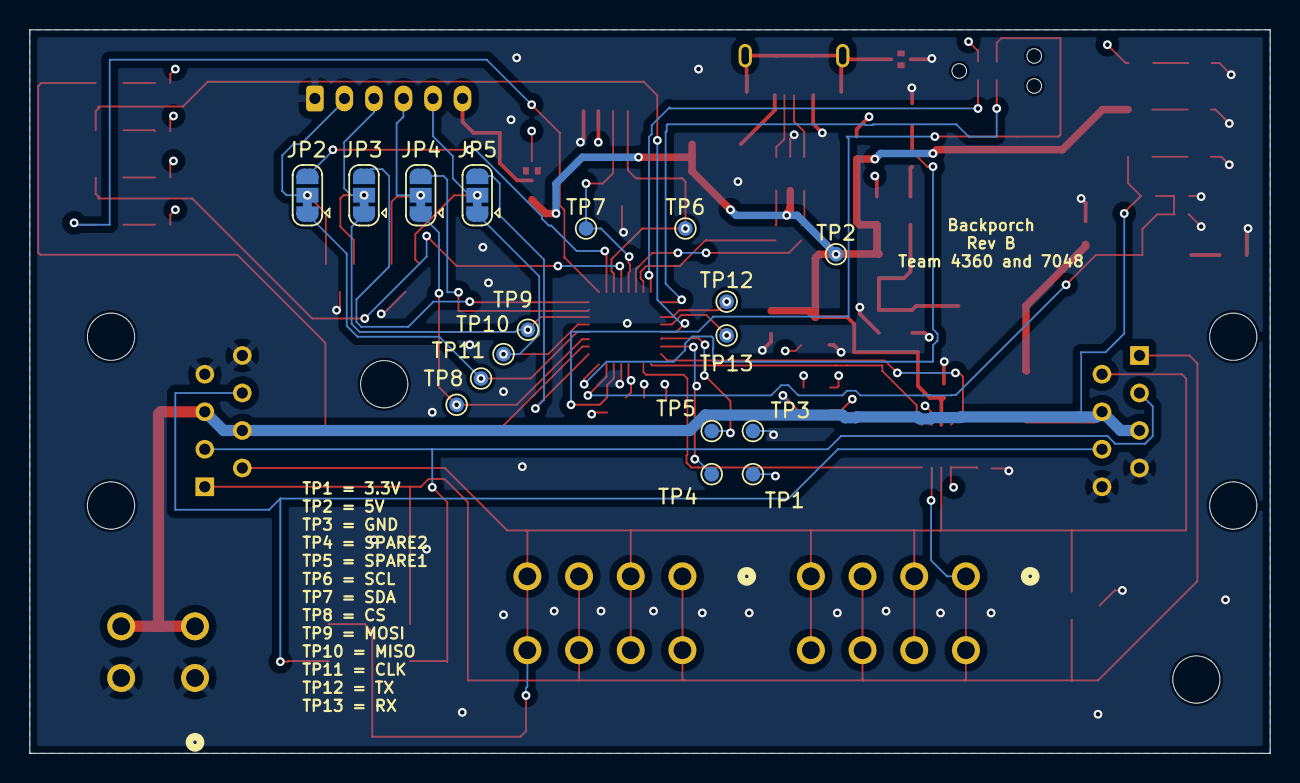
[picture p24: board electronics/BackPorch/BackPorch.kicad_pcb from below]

Board: 4 copper layers, 84.0 x 49.0 mm, 80 parts (17 on the bottom side), 58 nets.

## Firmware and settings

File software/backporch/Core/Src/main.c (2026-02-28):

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
/* Includes ------------------------------------------------------------------*/
#include "main.h"
#include "cmsis_os.h"
#include "usb_device.h"

/* USER CODE BEGIN Includes */
#include "usbd_cdc_if.h"
#include <stdlib.h>
#include <string.h>
#include "stm32g0xx_ll_adc.h"
#include <stdio.h>
#include "common.h"
#include "version.h"
#include "FreeRTOS.h"
#include "task.h"
#include "app_tof.h"
/* USER CODE END Includes */

typedef StaticQueue_t osStaticMessageQDef_t;
ADC_HandleTypeDef hadc1;

CRC_HandleTypeDef hcrc;

FDCAN_HandleTypeDef hfdcan1;

I2C_HandleTypeDef hi2c1;

IWDG_HandleTypeDef hiwdg;

TIM_HandleTypeDef htim1;
TIM_HandleTypeDef htim2;
TIM_HandleTypeDef htim3;

UART_HandleTypeDef huart5;

/* Definitions for defaultTask */
osThreadId_t defaultTaskHandle;
const osThreadAttr_t defaultTask_attributes = {
  .name = "defaultTask",
  .priority = (osPriority_t) osPriorityNormal,
  .stack_size = 128 * 4
};
/* Definitions for canRx */
osThreadId_t canRxHandle;
const osThreadAttr_t canRx_attributes = {
  .name = "canRx",
  .priority = (osPriority_t) osPriorityHigh,
  .stack_size = 128 * 4
};
/* Definitions for monTask */
osThreadId_t monTaskHandle;
const osThreadAttr_t monTask_attributes = {
  .name = "monTask",
  .priority = (osPriority_t) osPriorityLow,
  .stack_size = 1024 * 4
};
/* Definitions for canTx */
osThreadId_t canTxHandle;
const osThreadAttr_t canTx_attributes = {
  .name = "canTx",
  .priority = (osPriority_t) osPriorityBelowNormal,
  .stack_size = 128 * 4
};
/* Definitions for tof */
osThreadId_t tofHandle;
const osThreadAttr_t tof_attributes = {
  .name = "tof",
  .priority = (osPriority_t) osPriorityLow,
  .stack_size = 256 * 4
};
/* Definitions for tofQ */
osMessageQueueId_t tofQHandle;
uint8_t tofQBuffer[ 16 * sizeof( uint32_t ) ];
osStaticMessageQDef_t tofQControlBlock;
const osMessageQueueAttr_t tofQ_attributes = {
  .name = "tofQ",
  .cb_mem = &tofQControlBlock,
  .cb_size = sizeof(tofQControlBlock),
  .mq_mem = &tofQBuffer,
  .mq_size = sizeof(tofQBuffer)
};
/* USER CODE BEGIN PV */
osMutexId_t uartMutexHandle;
const osMutexAttr_t uartMutex_attributes = {
  .name = "uartMutex"
};
void uart5_puts(const char * str);
volatile int32_t pulse_width_1000deg = 0;
volatile int32_t enc1_count = 0;
volatile uint8_t enc1_prev_state = 0;
volatile uint32_t can_rx_msg_count = 0;
volatile uint32_t last_rx_id = 0;
uint8_t g_device_id = 0;
uint32_t hashed_id_ = 0;

void load_config() {
    BootConfig_t *cfg = (BootConfig_t *)BOOT_CONFIG_ADDR;
    if (cfg->magic == BOOT_CONFIG_MAGIC) {
        g_device_id = cfg->deviceID & 0x3F;
    } else {
        g_device_id = 0; // Default
    }
}

void save_config(uint8_t new_id) {
    //char msg[64];
    extern CRC_HandleTypeDef hcrc;
    
    /* Read existing config from flash */
    BootConfig_t* flashConfig = (BootConfig_t *)BOOT_CONFIG_ADDR;
    
    /* Prepare new config in RAM at the designated location */
    BootConfig_t* ramConfig = RAM_CONFIG_ADDR;
    
    /* Start with current flash config if valid, otherwise zero */
    if (flashConfig->magic == BOOT_CONFIG_MAGIC) {
        memcpy(ramConfig, flashConfig, sizeof(BootConfig_t));
    } else {
        memset(ramConfig, 0, sizeof(BootConfig_t));
    }
    
    /* Update the deviceID */
    ramConfig->magic = BOOT_CONFIG_MAGIC;
    ramConfig->deviceID = new_id;
    
    /* Calculate CRC over appSize through reserved[] (exclude magic and crc fields) */
    /* CRC covers: appSize, appCrc, deviceID, reserved[1004] = 1016 bytes = 254 words */
    ramConfig->crc = HAL_CRC_Calculate(&hcrc, (uint32_t*)&ramConfig->appSize, 
                                       (sizeof(BootConfig_t) - 8) / 4); /* 8 = sizeof(magic) + sizeof(crc) */
    
    /* Set the magic word to trigger config programming on reboot */
    *MAGIC_WORD_ADDR = MAGIC_WORD_PROGRAM_CONFIG;
    
    __disable_irq();
    HAL_NVIC_SystemReset();
}
/* USER CODE END PV */

void SystemClock_Config(void);
static void MX_GPIO_Init(void);
static void MX_ADC1_Init(void);
static void MX_FDCAN1_Init(void);
static void MX_TIM3_Init(void);
static void MX_I2C1_Init(void);
static void MX_TIM1_Init(void);
static void MX_USART5_UART_Init(void);
static void MX_TIM2_Init(void);
static void MX_IWDG_Init(void);
static void MX_CRC_Init(void);
void StartDefaultTask(void *argument);
void canRxTask(void *argument);
void StartMonTask(void *argument);
void canTxTask(void *argument);
void tofTask(void *argument);

/* USER CODE BEGIN 0 */
void txstring(const char * str)
{
    int len = strlen(str);
    CDC_Transmit_FS((uint8_t*)str, len);
}

void uart5_puts(const char * str)
{
    if (uartMutexHandle != NULL) {
        osMutexAcquire(uartMutexHandle, osWaitForever);
    }
    HAL_UART_Transmit(&huart5, (uint8_t*)str, strlen(str), 100);
    if (uartMutexHandle != NULL) {
        osMutexRelease(uartMutexHandle);
    }
}

void configureTimerForRunTimeStats(void)
{
  // TIM2 is already configured and started for input capture
}

unsigned long getRunTimeCounterValue(void)
{
  return TIM2->CNT;
}

uint32_t murmur3_32(const uint8_t* key, size_t len, uint32_t seed)
{
  uint32_t h = seed;
  uint32_t k;
  const uint32_t* data = (const uint32_t*)key;
  const size_t nblocks = len / 4;

  for (size_t i = 0; i < nblocks; i++) {
    k = data[i];
    k *= 0xcc9e2d51;
    k = (k << 15) | (k >> 17);
    k *= 0x1b873593;
    h ^= k;
    h = (h << 13) | (h >> 19);
    h = h * 5 + 0xe6546b64;
  }

  const uint8_t* tail = (const uint8_t*)(key + nblocks * 4);
  k = 0;
  switch (len & 3) {
    case 3: k ^= tail[2] << 16;
    case 2: k ^= tail[1] << 8;
    case 1: k ^= tail[0];
            k *= 0xcc9e2d51;
            k = (k << 15) | (k >> 17);
            k *= 0x1b873593;
            h ^= k;
  }

  h ^= len;
  h ^= h >> 16;
  h *= 0x85ebca6b;
  h ^= h >> 13;
  h *= 0xc2b2ae35;
  h ^= h >> 16;
  return h;
}

/* USER CODE END 0 */

/**
  * @brief  The application entry point.
  * @retval int
  */
int main(void)
{

  /* MCU Configuration--------------------------------------------------------*/

  /* Reset of all peripherals, Initializes the Flash interface and the Systick. */
  HAL_Init();

  /* Configure the system clock */
  SystemClock_Config();

  /* Initialize all configured peripherals */
  MX_GPIO_Init();
  MX_ADC1_Init();
  MX_FDCAN1_Init();
  MX_TIM3_Init();
  MX_I2C1_Init();
  MX_TIM1_Init();
  MX_USART5_UART_Init();
  MX_TIM2_Init();
  MX_IWDG_Init();
  MX_CRC_Init();
  /* USER CODE BEGIN 2 */
  HAL_ADCEx_Calibration_Start(&hadc1);
  HAL_IWDG_Refresh(&hiwdg); // Early refresh

  load_config(); // Load device ID from flash

  HAL_GPIO_WritePin(LED1_GPIO_Port, LED1_Pin, 1);
  HAL_GPIO_WritePin(LED2_GPIO_Port, LED2_Pin, 1);

  /* USER CODE END 2 */

  /* Init scheduler */
  osKernelInitialize();

  /* USER CODE BEGIN RTOS_MUTEX */
  /* add mutexes, ... */
  uartMutexHandle = osMutexNew(&uartMutex_attributes);
  /* USER CODE END RTOS_MUTEX */

  /* USER CODE BEGIN RTOS_SEMAPHORES */
  /* add semaphores, ... */
  /* USER CODE END RTOS_SEMAPHORES */

  /* USER CODE BEGIN RTOS_TIMERS */
  /* start timers, add new ones, ... */
  /* USER CODE END RTOS_TIMERS */

  /* Create the queue(s) */
  /* creation of tofQ */
  tofQHandle = osMessageQueueNew (16, sizeof(uint32_t), &tofQ_attributes);

  /* USER CODE BEGIN RTOS_QUEUES */
  /* add queues, ... */
  /* USER CODE END RTOS_QUEUES */

  /* Create the thread(s) */
  /* creation of defaultTask */
  defaultTaskHandle = osThreadNew(StartDefaultTask, NULL, &defaultTask_attributes);

  /* creation of canRx */
  canRxHandle = osThreadNew(canRxTask, NULL, &canRx_attributes);

  /* creation of monTask */
  monTaskHandle = osThreadNew(StartMonTask, NULL, &monTask_attributes);

  /* creation of canTx */
  canTxHandle = osThreadNew(canTxTask, NULL, &canTx_attributes);

  /* creation of tof */
  tofHandle = osThreadNew(tofTask, NULL, &tof_attributes);

  /* USER CODE BEGIN RTOS_THREADS */
  /* add threads, ... */
  /* USER CODE END RTOS_THREADS */

  /* USER CODE BEGIN RTOS_EVENTS */
  uint32_t uid[3];
  uid[0] = HAL_GetUIDw0();
  uid[1] = HAL_GetUIDw1();
  uid[2] = HAL_GetUIDw2();
  hashed_id_ = murmur3_32((uint8_t*)uid, 12, 0);
  /* USER CODE END RTOS_EVENTS */

  /* Start scheduler */
  osKernelStart();

  /* We should never get here as control is now taken by the scheduler */

  /* Infinite loop */
  /* USER CODE BEGIN WHILE */
  while (1)
  {
    /* USER CODE END WHILE */

    /* USER CODE BEGIN 3 */
  }
  /* USER CODE END 3 */
}

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
/* USER CODE BEGIN 4 */

void HAL_TIM_IC_CaptureCallback(TIM_HandleTypeDef *htim)
{
  if (htim->Instance == TIM2 && htim->Channel == HAL_TIM_ACTIVE_CHANNEL_4)
  {
    uint32_t t_rise = HAL_TIM_ReadCapturedValue(htim, TIM_CHANNEL_3);
    uint32_t t_fall = HAL_TIM_ReadCapturedValue(htim, TIM_CHANNEL_4);

    uint32_t pulse_width = t_fall - t_rise;
    /*
    Refer to this for the Rev Through Bore Encoder Pulse Width specification:
    https://docs.broadcom.com/doc/pub-005892

    1025 us is the max value. We have a 64 MHz clock, therefore the max value should be 65600
    PWM period: 1025

      t=0us  t=1us                             t=1024us  t=1025us
        |      |                                   |         |
        v      v                                   v         v
      +---+                                                +---+
PWM   |   |                                                |   |  Absolute position = 16'h0
      +   +------------------------------------------------+   +
      :   :                                                :   :
      :   :                                                :   :
      +   +------------------------------------------------+   +
PWM   |                                                        |  Absolute position = 16'hFFFF
      +---+                                                +---+
        ^      ^                                   ^         ^
        |      |                                   |         |
      t=0us  t=1us                             t=1024us  t=1025us
    */ 
    if (pulse_width > 65600)
    {
      pulse_width = t_rise - t_fall;
    }
    int pulse_width_us = pulse_width / 64;
    pulse_width_1000deg = (pulse_width_us * 36000) / 1025;
  }
  else if (htim->Instance == TIM3)
  {
    // Software Quadrature Decoder for TIM3 CH3 (PB0) and CH4 (PB1)
    // TIM3_CH3 is PB0, TIM3_CH4 is PB1
    uint8_t a = (GPIOB->IDR & GPIO_PIN_0) ? 1 : 0;
    uint8_t b = (GPIOB->IDR & GPIO_PIN_1) ? 1 : 0;
    uint8_t curr_state = (a << 1) | b;
    static const int8_t q_table[16] = {0, 1, -1, 0, -1, 0, 0, 1, 1, 0, 0, -1, 0, -1, 1, 0};
    
    enc1_count += q_table[(enc1_prev_state << 2) | curr_state];
    enc1_prev_state = curr_state;
  }
}

/* USER CODE END 4 */

/* USER CODE BEGIN Header_StartDefaultTask */
/**
  * @brief  Function implementing the defaultTask thread.
  * @param  argument: Not used
  * @retval None
  */
/* USER CODE END Header_StartDefaultTask */
void StartDefaultTask(void *argument)
{
  /* init code for USB_Device */
  MX_USB_Device_Init();
  /* USER CODE BEGIN 5 */

  /* Infinite loop */
  for(;;)
  {
    osDelay(100);
  }
  /* USER CODE END 5 */
}

/* USER CODE BEGIN Header_canRxTask */
/**
* @brief Function implementing the canRx thread.
* @param argument: Not used
* @retval None
*/
/* USER CODE END Header_canRxTask */
void canRxTask(void *argument)
{
  /* USER CODE BEGIN canRxTask */
  HAL_GPIO_WritePin(CAN_STB_GPIO_Port, CAN_STB_Pin, GPIO_PIN_RESET);

  HAL_FDCAN_Stop(&hfdcan1); // Ensure it's stopped before configuring filter

  FDCAN_FilterTypeDef sFilterConfig;
  sFilterConfig.IdType = FDCAN_EXTENDED_ID;
  sFilterConfig.FilterIndex = 0;
  sFilterConfig.FilterType = FDCAN_FILTER_MASK;
  sFilterConfig.FilterConfig = FDCAN_FILTER_TO_RXFIFO0;
  // Temporary: Accept ALL messages for debugging
  sFilterConfig.FilterID1 = 0;
  sFilterConfig.FilterID2 = 0;
  HAL_FDCAN_ConfigFilter(&hfdcan1, &sFilterConfig);

  HAL_FDCAN_Start(&hfdcan1);


  /* Infinite loop */
  for(;;)
  {
    // Handle Incoming CAN messages
    FDCAN_RxHeaderTypeDef rxHeader;
    uint8_t rxData[8];
    while (HAL_FDCAN_GetRxMessage(&hfdcan1, FDCAN_RX_FIFO0, &rxHeader, rxData) == HAL_OK)
    {
        can_rx_msg_count++;
        last_rx_id = rxHeader.Identifier;
        if (rxHeader.Identifier == WPILIB_HEARTBEAT_ID)
        {
            HAL_GPIO_TogglePin(CAN_STATUS_GPIO_Port, CAN_STATUS_Pin);
        }

        uint32_t apiClass = (rxHeader.Identifier >> 10) & 0x3F;
        uint32_t devId = rxHeader.Identifier & 0x3F;

        if (apiClass == 0 && devId == 0) { // System Broadcast Class
            uint32_t target_uid = *((uint32_t *)&rxData[0]);
            if (target_uid == hashed_id_) {
                uint8_t new_id = rxData[4] & 0x3F;
                save_config(new_id); // Does not return - reboots to program config via bootloader
            }
        }

        if (apiClass == 1 && devId == g_device_id) { // Control Class for OUR device
            uint8_t cmd = rxData[0];
            if (cmd == CAN_CMD_START) {
                // Send ACK 0xAA 0x01 to indicate app-to-bootloader transition
                FDCAN_TxHeaderTypeDef txHeader;
                txHeader.Identifier = rxHeader.Identifier;
                txHeader.IdType = FDCAN_EXTENDED_ID;
                txHeader.TxFrameType = FDCAN_DATA_FRAME;
                txHeader.DataLength = FDCAN_DLC_BYTES_8;
                txHeader.ErrorStateIndicator = FDCAN_ESI_ACTIVE;
                txHeader.BitRateSwitch = FDCAN_BRS_OFF;
                txHeader.FDFormat = FDCAN_CLASSIC_CAN;
                txHeader.TxEventFifoControl = FDCAN_NO_TX_EVENTS;
                txHeader.MessageMarker = 0; 
                
                uint8_t ackData[8] = {0xAA, 0x01, 0, 0, 0, 0, 0, 0};
                HAL_FDCAN_AddMessageToTxFifoQ(&hfdcan1, &txHeader, ackData);
                
                // Set Magic Word and Reboot (survives bootloader startup at this address)
                *MAGIC_WORD_ADDR = MAGIC_WORD_PROGRAM_FW;
                __disable_irq();
                HAL_NVIC_SystemReset();
              } 
            }
    }
    osDelay(1);
  }
  /* USER CODE END canRxTask */
}

/* USER CODE BEGIN Header_StartMonTask */
/**
* @brief Function implementing the monTask thread.
* @param argument: Not used
* @retval None
*/
static int compareTaskStatus(const void *a, const void *b)
{
    const TaskStatus_t *p1 = (const TaskStatus_t *)a;
    const TaskStatus_t *p2 = (const TaskStatus_t *)b;
    if (p1->xTaskNumber < p2->xTaskNumber) return -1;
    if (p1->xTaskNumber > p2->xTaskNumber) return 1;
    return 0;
}
/* USER CODE END Header_StartMonTask */
void StartMonTask(void *argument)
{
  /* USER CODE BEGIN StartMonTask */
  char stats_buffer[1024];
  /* Infinite loop */
  for(;;)
  {
    osDelay(1000);
    HAL_IWDG_Refresh(&hiwdg);
    
    // Clear screen and home cursor
    uart5_puts("\r\n\r\n");
    
    // Header
    uart5_puts("================ SYSTEM PERFORMANCE MONITOR ================\r\n");
    
    // Stack and Task Info
    uart5_puts("--- Task Status ---\r\n");
    uart5_puts("Name             State  Prio  FreeStack(Words)  ID\r\n");
    uart5_puts("----------------------------------------------------------\r\n");
    vTaskList(stats_buffer);
    uart5_puts(stats_buffer);

    // CPU Usage
    uart5_puts("\r\n--- CPU Usage ---\r\n");
    uart5_puts("Name             Abs Time       Time %\r\n");
    uart5_puts("----------------------------------------------------------\r\n");
    
    UBaseType_t uxArraySize = uxTaskGetNumberOfTasks();
    TaskStatus_t *pxTaskStatusArray = pvPortMalloc(uxArraySize * sizeof(TaskStatus_t));

    if (pxTaskStatusArray != NULL) {
        uint32_t ulTotalRunTime;
        uxArraySize = uxTaskGetSystemState(pxTaskStatusArray, uxArraySize, &ulTotalRunTime);

        if (ulTotalRunTime > 0) {
            // Sort by Task ID (xTaskNumber)
            qsort(pxTaskStatusArray, uxArraySize, sizeof(TaskStatus_t), compareTaskStatus);
            
            for (UBaseType_t x = 0; x < uxArraySize; x++) {
                uint32_t ulStatsAsPercentage = (uint32_t)((uint64_t)pxTaskStatusArray[x].ulRunTimeCounter * 10000 / ulTotalRunTime);
                uint32_t integral = ulStatsAsPercentage / 100;
                uint32_t fractional = ulStatsAsPercentage % 100;
                
                sprintf(stats_buffer, "%-16s %-14lu %2lu.%02lu%%\r\n",
                        pxTaskStatusArray[x].pcTaskName,
                        (unsigned long)pxTaskStatusArray[x].ulRunTimeCounter,
                        (unsigned long)integral, (unsigned long)fractional);
                uart5_puts(stats_buffer);
            }
        }
        vPortFree(pxTaskStatusArray);
    }
 
    //Heap Info
    uart5_puts("\r\n--- Memory Info ---\r\n");
    char heap_str[64];
    sprintf(heap_str, "Free Heap: %u bytes\r\n", (unsigned int)xPortGetFreeHeapSize());
    uart5_puts(heap_str);
    
    snprintf(stats_buffer, sizeof(stats_buffer),
             "\r\n--- CAN Debug ---\r\n"
             "CAN Rx Count: %lu\r\n"
             "Last Rx ID: 0x%08lX\r\n",
             (unsigned long)can_rx_msg_count, (unsigned long)last_rx_id);
    uart5_puts(stats_buffer);

    HAL_GPIO_TogglePin(SYS_STATUS_GPIO_Port, SYS_STATUS_Pin);

  }
  /* USER CODE END StartMonTask */
}
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

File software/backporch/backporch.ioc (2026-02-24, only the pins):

Mcu.UserName=STM32G0B1KBUx
PA0.GPIO_Label=VIN_MEASURE
PA0.Signal=ADC1_IN0
PA1.GPIO_Label=CURRENT_5V
PA1.Signal=ADC1_IN1
PA10.Signal=I2C1_SDA
PA13.Signal=SYS_SWDIO
PA14-BOOT0.Signal=SYS_SWCLK
PA2.Signal=S_TIM2_CH3
PA3.GPIO_Label=SYS_STATUS
PA3.Signal=GPIO_Output
PA8.GPIO_Label=TB_ENCI
PA8.Signal=S_TIM1_CH1
PA9.Signal=I2C1_SCL
PB0.GPIO_Label=TB_TIMA
PB0.Signal=S_TIM3_CH3
PB1.GPIO_Label=TB_TIMB
PB1.Signal=S_TIM3_CH4
PB2.GPIO_Label=LED2
PB2.Signal=GPIO_Output
PB3.Signal=USART5_TX
PB4.Signal=USART5_RX
PB5.GPIO_Label=CAN_STATUS
PB5.Signal=GPIO_Output
PB6.GPIO_Label=SPARE1
PB6.Signal=GPIO_Output
PB7.GPIO_Label=SPARE2
PB7.Signal=GPIO_Output
PB8.Signal=FDCAN1_RX
PB9.Signal=FDCAN1_TX
PC6.GPIO_Label=LED1
PC6.Signal=GPIO_Output

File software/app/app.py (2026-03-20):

import can
import struct
import threading
import time
import tkinter as tk
import zlib
import logging
import socket
from collections import deque
from tkinter import ttk, filedialog

# Configure logging
logging.basicConfig(
    level=logging.DEBUG,
    format='%(asctime)s [%(levelname)s] %(threadName)s: %(message)s',
    handlers=[
        logging.FileHandler("can_monitor.log"),
        logging.StreamHandler()
    ]
)
logger = logging.getLogger(__name__)

class UDPBus:
    def __init__(self, ip, port):
        self.ip = ip
        self.port = port
        self.sock = socket.socket(socket.AF_INET, socket.SOCK_DGRAM)
        self.sock.settimeout(0.1)
        self.last_heartbeat = 0
        self._send_heartbeat()

    def _send_heartbeat(self):
        # Send a heartbeat so server knows where we are
        try:
            self.sock.sendto(struct.pack(">IB", 0, 0), (self.ip, self.port))
        except:
            pass
        self.last_heartbeat = time.time()

    def recv(self, timeout=None):
        if time.time() - self.last_heartbeat > 1.0:
            self._send_heartbeat()
            
        if timeout is not None:
            self.sock.settimeout(timeout)
        try:
            data, addr = self.sock.recvfrom(1024)
            if len(data) >= 5:
                can_id, length = struct.unpack(">IB", data[:5])
                payload = data[5:5+length]
                return can.Message(arbitration_id=can_id, data=payload, is_extended_id=True)
        except socket.timeout:
            pass
        except Exception as e:
            logger.error(f"UDPBus recv error: {e}")
        return None

    def send(self, msg):
        packet = struct.pack(">IB", msg.arbitration_id, len(msg.data)) + bytes(msg.data)
        self.sock.sendto(packet, (self.ip, self.port))
        logger.debug(f"UDPBus TX: ID=0x{msg.arbitration_id:08X} Len={len(msg.data)} to {self.ip}:{self.port}")

    def shutdown(self):
        self.sock.close()


class CanMonitorApp:
    def __init__(self, root):
        self.root = root
        self.root.title("BackPorch CAN Monitor & Bootloader")
        self.root.geometry("600x750")
        
        logger.info("Initializing CanMonitorApp")
        # Data storage and Multicast CAN
        self.devices = {} # device_id -> device_data
        self.can_handlers = [] # list of functions(msg)
        self.can_handlers.append(self.dispatch_to_devices)
        
        self.bin_path = tk.StringVar(value="")
        self.update_status = tk.StringVar(value="Idle")
        self.device_id = tk.IntVar(value=0)
        self.updating = False
        self.print_traffic = tk.BooleanVar(value=False)
        self.last_msg_time = time.time()
        self.total_bits = 0
        self.last_util_time = time.time()
        self.bus_util_str = tk.StringVar(value="Bus: 0.0% | 1s Avg: 0.0% | Max: 0.0%")
        self.util_history = deque(maxlen=10)
        self.max_bus_util = 0.0
        
        # Connection variables
        self.conn_type = tk.StringVar(value="CANable (slcan)")
        self.slcan_port = tk.StringVar(value="COM5")
        self.slcan_bitrate = tk.IntVar(value=1000000)
        self.udp_ip = tk.StringVar(value="10.TE.AM.2")
        self.udp_port = tk.IntVar(value=5900)
        
        self.running = False
        self.bus = None
        self.receive_thread = None

        self.setup_ui()
        self.update_ui()

    def connect_bus(self):
        if self.running:
            return
            
        try:
            if self.conn_type.get() == "CANable (slcan)":
                logger.info(f"Opening CAN bus on {self.slcan_port.get()} at {self.slcan_bitrate.get()}bps")
                self.bus = can.interface.Bus(bustype='slcan', channel=self.slcan_port.get(), bitrate=self.slcan_bitrate.get())
            else:
                logger.info(f"Opening UDP bus at {self.udp_ip.get()}:{self.udp_port.get()}")
                self.bus = UDPBus(self.udp_ip.get(), self.udp_port.get())
                
            self.running = True
            self.btn_connect.config(state="disabled")
            self.btn_disconnect.config(state="normal")
            
            self.receive_thread = threading.Thread(target=self.receive_can, name="ReceiveThread", daemon=True)
            self.util_history.clear()
            self.max_bus_util = 0.0
            self.receive_thread.start()
        except Exception as e:
            logger.error(f"Error opening CAN bus: {e}")
            self.running = False
            
    def disconnect_bus(self):
        self.running = False
        if self.receive_thread:
            self.receive_thread.join(timeout=1.0)
            self.receive_thread = None
        if self.bus:
            if hasattr(self.bus, 'shutdown'):
                self.bus.shutdown()
            self.bus = None
        
        self.btn_connect.config(state="normal")
        self.btn_disconnect.config(state="disabled")

    def setup_ui(self):
        style = ttk.Style()
        style.configure("Header.TLabel", font=("Arial", 12, "bold"))
        style.configure("Data.TLabel", font=("Consolas", 10))

        # Connection Section
        frame_conn = ttk.LabelFrame(self.root, text=" Connection ", padding=10)
        frame_conn.pack(fill="x", padx=10, pady=5)
        
        conn_row1 = ttk.Frame(frame_conn)
        conn_row1.pack(fill="x", pady=2)
        ttk.Radiobutton(conn_row1, text="CANable (slcan)", variable=self.conn_type, value="CANable (slcan)").pack(side="left")
        ttk.Label(conn_row1, text="Port:").pack(side="left", padx=(10,2))
        ttk.Entry(conn_row1, textvariable=self.slcan_port, width=8).pack(side="left")
        ttk.Label(conn_row1, text="Bitrate:").pack(side="left", padx=(10,2))
        ttk.Entry(conn_row1, textvariable=self.slcan_bitrate, width=10).pack(side="left")
        
        conn_row2 = ttk.Frame(frame_conn)
        conn_row2.pack(fill="x", pady=2)
        ttk.Radiobutton(conn_row2, text="UDP Server (Backporch)", variable=self.conn_type, value="UDP").pack(side="left")
        ttk.Label(conn_row2, text="IP:").pack(side="left", padx=(10,2))
        ttk.Entry(conn_row2, textvariable=self.udp_ip, width=15).pack(side="left")
        ttk.Label(conn_row2, text="Port:").pack(side="left", padx=(10,2))
        ttk.Entry(conn_row2, textvariable=self.udp_port, width=8).pack(side="left")
        
        conn_row3 = ttk.Frame(frame_conn)
        conn_row3.pack(fill="x", pady=5)
        self.btn_connect = ttk.Button(conn_row3, text="Connect", command=self.connect_bus)
        self.btn_connect.pack(side="left", padx=5)
        self.btn_disconnect = ttk.Button(conn_row3, text="Disconnect", command=self.disconnect_bus, state="disabled")
        self.btn_disconnect.pack(side="left", padx=5)

        # Bootloader Section
        frame_boot = ttk.LabelFrame(self.root, text=" Bootloader ", padding=10)
        frame_boot.pack(fill="x", padx=10, pady=5)
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

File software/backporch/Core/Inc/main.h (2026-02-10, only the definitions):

#define CAN_STB_Pin GPIO_PIN_14
#define CAN_STB_GPIO_Port GPIOC
#define VIN_MEASURE_Pin GPIO_PIN_0
#define VIN_MEASURE_GPIO_Port GPIOA
#define CURRENT_5V_Pin GPIO_PIN_1
#define CURRENT_5V_GPIO_Port GPIOA
#define SYS_STATUS_Pin GPIO_PIN_3
#define SYS_STATUS_GPIO_Port GPIOA
#define TB_TIMA_Pin GPIO_PIN_0
#define TB_TIMA_GPIO_Port GPIOB
#define TB_TIMB_Pin GPIO_PIN_1
#define TB_TIMB_GPIO_Port GPIOB
#define LED2_Pin GPIO_PIN_2
#define LED2_GPIO_Port GPIOB
#define TB_ENCI_Pin GPIO_PIN_8
#define TB_ENCI_GPIO_Port GPIOA
#define LED1_Pin GPIO_PIN_6
#define LED1_GPIO_Port GPIOC
#define CAN_STATUS_Pin GPIO_PIN_5
#define CAN_STATUS_GPIO_Port GPIOB
#define SPARE1_Pin GPIO_PIN_6
#define SPARE1_GPIO_Port GPIOB
#define SPARE2_Pin GPIO_PIN_7
#define SPARE2_GPIO_Port GPIOB

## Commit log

2025-06-20 Actually checked in the files.
    [2601-1102.stp, 2601-1104.stp, 54602-908LF.step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]
2026-02-10 Pulling Rev B into main (#1)
    * Planning on ordering more back porches.
    * Various updates to the footprints. Added datasheets.
    * Added the software.
    * Verified CAN, voltage input, current reading although the resistor is off, and temperature reading.
    * Many updates to get things dialed in. Have the ABS signal working. But there is a small glitch to it.
    * Inc encoder is now working as well.
    * Added a bootloader.
    * Bootloader is working to the point it can push new images into app code space.
    * Refactored the CAN messages. Programming is working, at least pushing code. Build version strings are working correctly.
    * Refactored the CAN messages. Programming is working, at least pushing code. B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
    [2601-1102.stp, 2601-1104.stp, 54602-908LF.step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]
2026-02-16 Rev b (#2)
    * Refactored the CAN messages. Programming is working, at least pushing code. Build version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
2026-02-22 Added the back porch lite devices.
    [BackPorch-B_Cu.gbr, BackPorch-B_Mask.gbr, BackPorch-B_Paste.gbr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]
2026-02-22 Added the backporch lite devices.
    [BackPorch-B_Cu.gbr, BackPorch-B_Mask.gbr, BackPorch-B_Paste.gbr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]
2026-02-22 Added a limit switch feature. TODO: Add the ability to switch between I2C/TOF mode and GPIO Limit switch mode.
2026-02-22 Minor changes to fix the CPU Usage stats.
    [main.c]
2026-02-23 Added in the VL53L0C sensor library.
2026-02-24 Added in the TOF sensor.
2026-02-28 Added the TOF vs limit switch logic.
    [Backporch_holder_top.SLDPRT]
2026-03-20 Added a 3mf file for the backporch top.
    [Backporch_holder_top.3mf]
2026-03-20 I have the backporch_server working. It doesn't work to program code yet.
    [app.py]

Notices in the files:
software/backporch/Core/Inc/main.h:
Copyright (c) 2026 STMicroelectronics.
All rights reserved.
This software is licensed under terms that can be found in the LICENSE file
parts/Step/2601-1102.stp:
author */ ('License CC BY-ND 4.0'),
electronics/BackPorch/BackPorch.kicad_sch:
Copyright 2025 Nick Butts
